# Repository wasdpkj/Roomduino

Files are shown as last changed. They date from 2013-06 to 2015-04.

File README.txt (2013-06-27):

=================================
本作品采用知识共享 署名-非商业性使用-相同方式共享 3.0 未本地化版本 许可协议进行许可。
访问 http://creativecommons.org/licenses/by-nc-sa/3.0/ 查看该许可协议。
=================================

硬件：
主机：MCU：MEGA644PA，网络芯片：ENC28J60，RJ45网口：HR911105A，2.4G无线：nRF24L01，显示屏：NOKIA5110屏，红外接收头
副机：MCU：MEGA328P或者168PA，2.4G无线：nRF24L01，可控硅：BT136，光耦：MOC3041
{副机可以自行选择设计成节点式（既一个arduino+24L01控制一个开关节点）、还是单MCU多路式（既一个arduino+24L01控制四个开关）}

除了以上条件，你还需要一个路由器，一个YEELINK账号，和一个红外遥控器。

========================================================
软件：

配置：
比如我的路由器网关是192.168.1，那么主机程序段里设置成如下即可，第一个是主机的IP地址，这个要和本地网页中的IP地址匹配

static byte myip[] =
{
  192, 168, 1, 121
};
static byte gwip[] =
{
  192, 168, 1, 1
};
static byte dnsip[] =
{
  192, 168, 1, 1
};

然后YEELINK的ID：
urlBuf0[]是YEELINK控制开关地址，剩下的是四个节点，然后填好你的API就可以

char website[] PROGMEM = "api.yeelink.net";

char urlBuf0[] PROGMEM = "/v1.0/device/xxx/sensor/xxx/";

char urlBuf1[] PROGMEM = "/v1.0/device/xxx/sensor/xxx/";
char urlBuf2[] PROGMEM = "/v1.0/device/xxx/sensor/xxx/";
char urlBuf3[] PROGMEM = "/v1.0/device/xxx/sensor/xxx/";
char urlBuf4[] PROGMEM = "/v1.0/device/xxx/sensor/xxx/";

char apiKey[] PROGMEM = "U-ApiKey: xxx";

================================================

说说红外遥控的使用：
开机进入系统后：
按“1”“2”“3”“4”可以开关四路节点；
按“PLAY”也可以实现系统模式切换（YEELINK万维网控制还是本地手动控制）；
按“CH+”“CH-”“CH”可以选择相应节点并且执行倒计时功能。

按“EQ”即可进入设置，此时“0”为确认，“+”和“-”上下移动菜单，再次按“EQ”结束设置：
设置的第一项“CONFIG MOD”是切换系统模式，这个在主界面按PLAY也可以实现切换。
设置的第二项“CONFIG TIME”是预约开启的设置，选择对应节点后，第一项是否定时开启，第二项与第三项是定时开启的时间设置，第四项是定时开启的世界设置（单位分钟）。
设置的第三项“CONFIG DS”是倒计时的设置，选择对应节点后，即可设置倒计时时间（单位分钟），此时“+”“-”“NEXT”“PREV”分别是加1，减1，加10，减10。
设置的第四项“CONFIG CON”是配置节点用的，选择所需配置节点后，系统会提示按下你所需节点的配置按键2秒以上，此时你能看到节点上的状态灯快速闪烁的话，就配置成功了；对了，工作模式下，节点上的灯闪动次数对应着第几路。
设置的第五项“CONFIG INFO”是系统信息和about

================================================

关于本地局域网控制的web网页：
你可以用编辑器打开index.html，里面的“http://192.168.1.121”就是当前arduino主机对应的IP地址；
另外，由于jquery的安全限制，现在仅支持PC端谷歌浏览器和ios端的谷歌浏览器的正常使用。

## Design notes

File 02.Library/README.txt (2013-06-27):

pkj是自己写的简单库
功能是限定/跳转值的上下限

ethercard库的推送方式我自己改过

大概如下：
char website[] PROGMEM = "api.yeelink.net";
char urlBuf0[] PROGMEM = "/v1.0/device/xxx/sensor/xxx/";
char apiKey[] PROGMEM = "U-ApiKey: xxx";

static void my_result_cb (byte status, word off, word len)
{
  sscanf((char *)strstr((const char *)Ethernet::buffer + off, "\"value\""), "\"value\":%d", &yee[yeenum-1]);    //采集关键字数据
}

          ether.browseUrl(urlBuf, "datapoints", website, apiKey, my_result_cb);   //采集节点

          ether.httpPost (urlBuf, "datapoints", website, apiKey, "{\"value\":0}", my_result_cb);    //把节点推到关

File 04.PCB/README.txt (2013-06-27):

重点说一下“副机 多路式”这个PCB
此PCB设计了ISP刷机口，预留了24L01插口、霍尔元件接口、SD卡、音频口、串口。随你怎么用

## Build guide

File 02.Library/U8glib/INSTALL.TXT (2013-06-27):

U8GLIB
http://code.google.com/p/u8glib/

Install instructions for the Arduino environment.

  1. Unzip u8glib_arduino_vX.XX.zip into the "libraries" folder
  2. Start Arduino IDE

Install instructions for the Chipkit (Arduino) environment.

  1. cd <mpide-... path>/libraries
  2. unzip u8glib_arduino_vX.XX.zip
  3. cd <mpide-... path>///hardware/pic32/libraries
  4. again: u8glib_arduino_vX.XX.zip
  5. Open hardware/pic32/cores/pic32/Print.h
	  Remove line
	    #define BYTE 0
	  from the file, use PRINT_BYTE instead of BYTE.

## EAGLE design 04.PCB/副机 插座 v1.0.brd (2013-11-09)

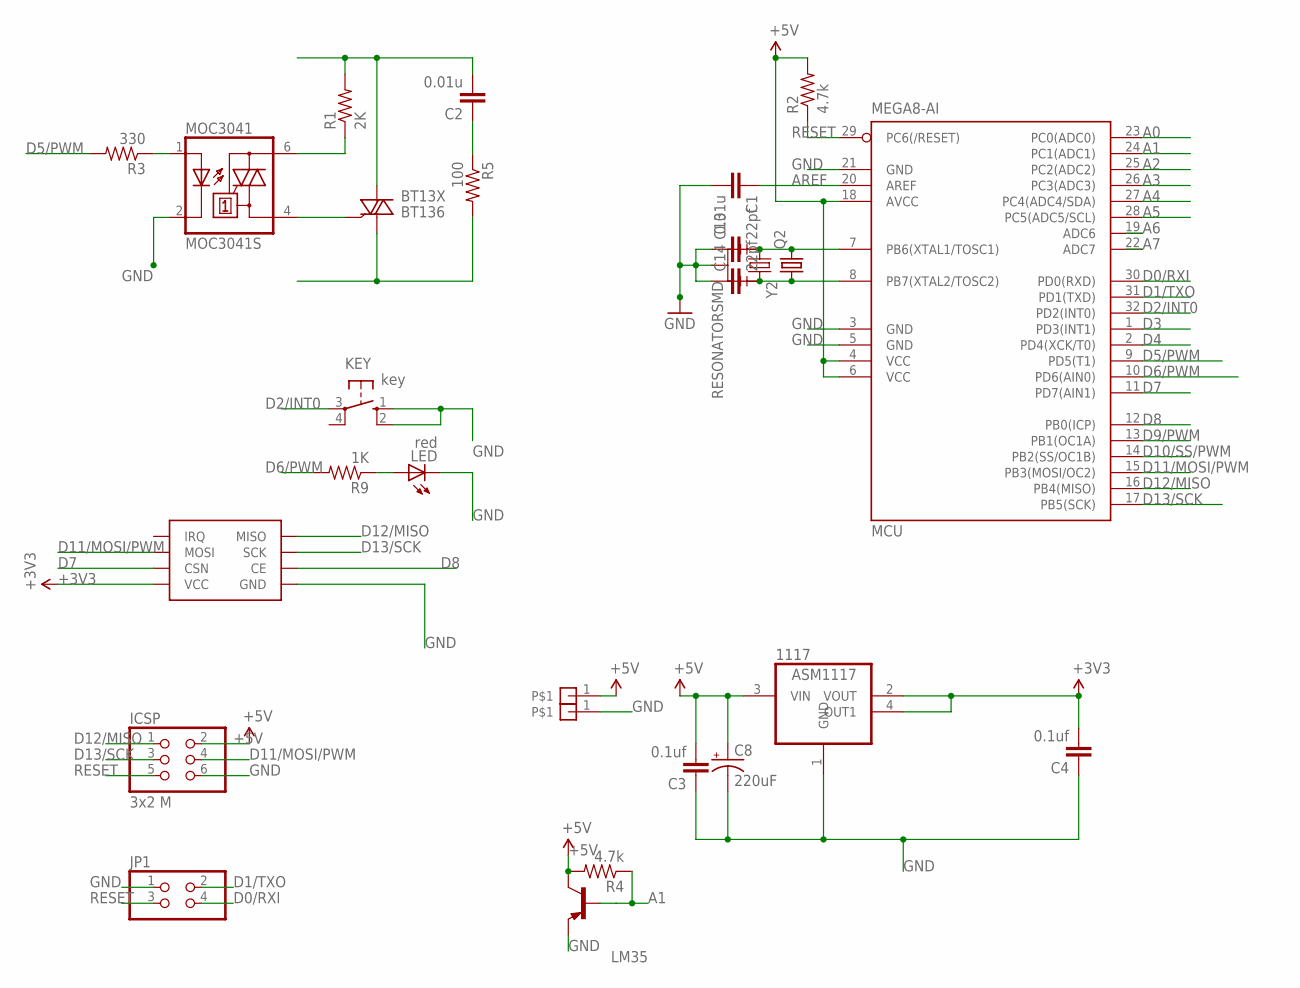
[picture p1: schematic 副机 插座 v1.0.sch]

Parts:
1117: ASM1117; SOT223
BT13X: BT136; TO252
C1: 0.01u; 0603-CAP
C2: 0.01u; C050-024X044
C3, C4: 0.1uf; 0603-CAP
C8: 220uF; EIA3528
C13, C14: 22pf; 0603-CAP
ICSP: 3x2 M; 2X03
JP1: PINHD-2X2; 2X02
KEY: key; B3F-10XX; MPN B3F-1000
LED: red; LED3MM
LM35: -PNP-TO92-E1; TO92-E1
MCU: MEGA8-AI; TQFP32-08
MOC3041: MOC3041S; DIL6-SMD; MPN MOC3041S-M
Q2: CRYSTALHC49S; HC49/S
R1: 2K; AXIAL-0.3
R2, R4: 4.7k; 0603-RES
R3: 330; 0603-RES
R5: 100; AXIAL-0.3
R9: 1K; 0603-RES
U$3, U$4: PIN1
U$6: NRF
Y2: RESONATORSMD; RESONATOR-SMD

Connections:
+3V3: 1117.2 (VOUT), 1117.4 (OUT1), C4.2, U$6.P$2 (VCC)
+5V: 1117.3 (VIN), C3.2, C8.A (+), ICSP.2, LM35.1 (C), MCU.4 (VCC), MCU.6 (VCC), MCU.18 (AVCC), R2.2, R4.2, U$3.1
A0: MCU.23 (PC0(ADC0))
A1: LM35.2 (B), MCU.24 (PC1(ADC1)), R4.1
A2: MCU.25 (PC2(ADC2))
A3: MCU.26 (PC3(ADC3))
A4: MCU.27 (PC4(ADC4/SDA))
A5: MCU.28 (PC5(ADC5/SCL))
A6: MCU.19 (ADC6)
A7: MCU.22 (ADC7)
AREF: C1.1, MCU.20 (AREF)
D0/RXI: JP1.4, MCU.30 (PD0(RXD))
D1/TXO: JP1.2, MCU.31 (PD1(TXD))
D2/INT0: KEY.3, MCU.32 (PD2(INT0))
D3: MCU.1 (PD3(INT1))
D4: MCU.2 (PD4(XCK/T0))
D5/PWM: MCU.9 (PD5(T1)), R3.2
D6/PWM: MCU.10 (PD6(AIN0)), R9.2
D7: MCU.11 (PD7(AIN1)), U$6.P$4 (CSN)
D8: MCU.12 (PB0(ICP)), U$6.P$3 (CE)
D9/PWM: MCU.13 (PB1(OC1A))
D10/SS/PWM: MCU.14 (PB2(SS/OC1B))
D11/MOSI/PWM: ICSP.4, MCU.15 (PB3(MOSI/OC2)), U$6.P$6 (MOSI)
D12/MISO: ICSP.1, MCU.16 (PB4(MISO)), U$6.P$7 (MISO)
D13/SCK: ICSP.3, MCU.17 (PB5(SCK)), U$6.P$5 (SCK)
GND: 1117.1 (GND), C1.2, C3.1, C4.1, C8.C (-), C13.1, C14.1, ICSP.6, JP1.1, KEY.1 (S), KEY.2 (S1), LED.K (C), LM35.3 (E), MCU.3 (GND), MCU.5 (GND), MCU.21 (GND), MOC3041.2 (C), U$4.1, U$6.P$1 (GND), Y2.2
IN: BT13X.3 (A2), C2.2, R1.P$2 (2)
unnamed: MOC3041.6 (A2), R1.P$1 (1)
unnamed: BT13X.2 (G), MOC3041.4 (A1)
unnamed: C2.1, R5.P$1 (1)
unnamed: LED.A, R9.1
unnamed: C13.2, MCU.7 (PB6(XTAL1/TOSC1)), Q2.2, Y2.1
unnamed: C14.2, MCU.8 (PB7(XTAL2/TOSC2)), Q2.1, Y2.3
OUT: BT13X.1 (A1), R5.P$2 (2)
P1: MOC3041.1 (A), R3.1
RESET: ICSP.5, JP1.3, MCU.29 (PC6(/RESET)), R2.1

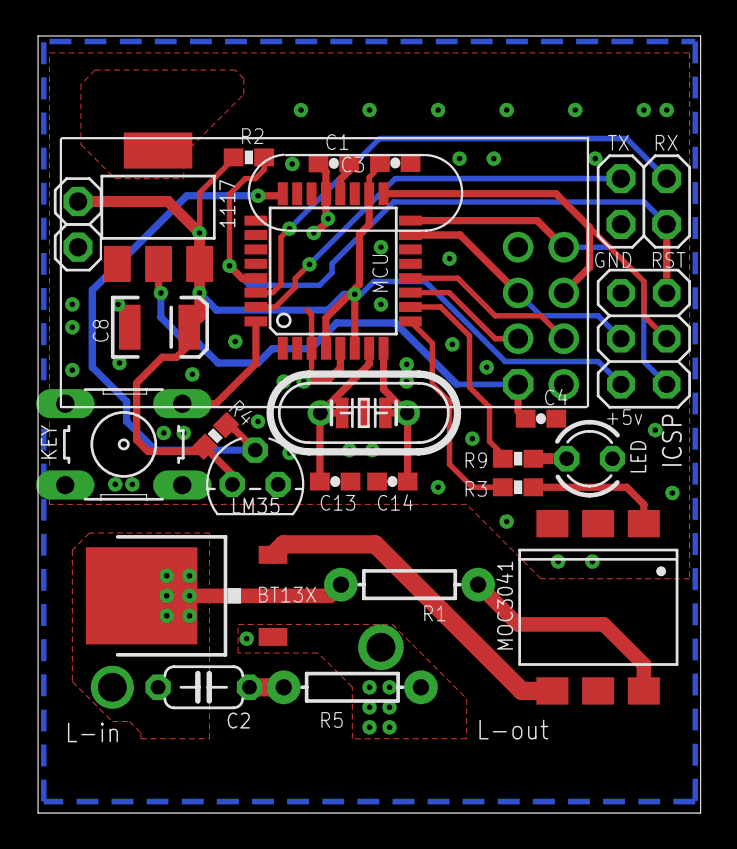
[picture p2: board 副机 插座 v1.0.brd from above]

Board: 2 copper layers, 36.8 x 43.2 mm, 27 parts (0 on the bottom side), 25 nets.

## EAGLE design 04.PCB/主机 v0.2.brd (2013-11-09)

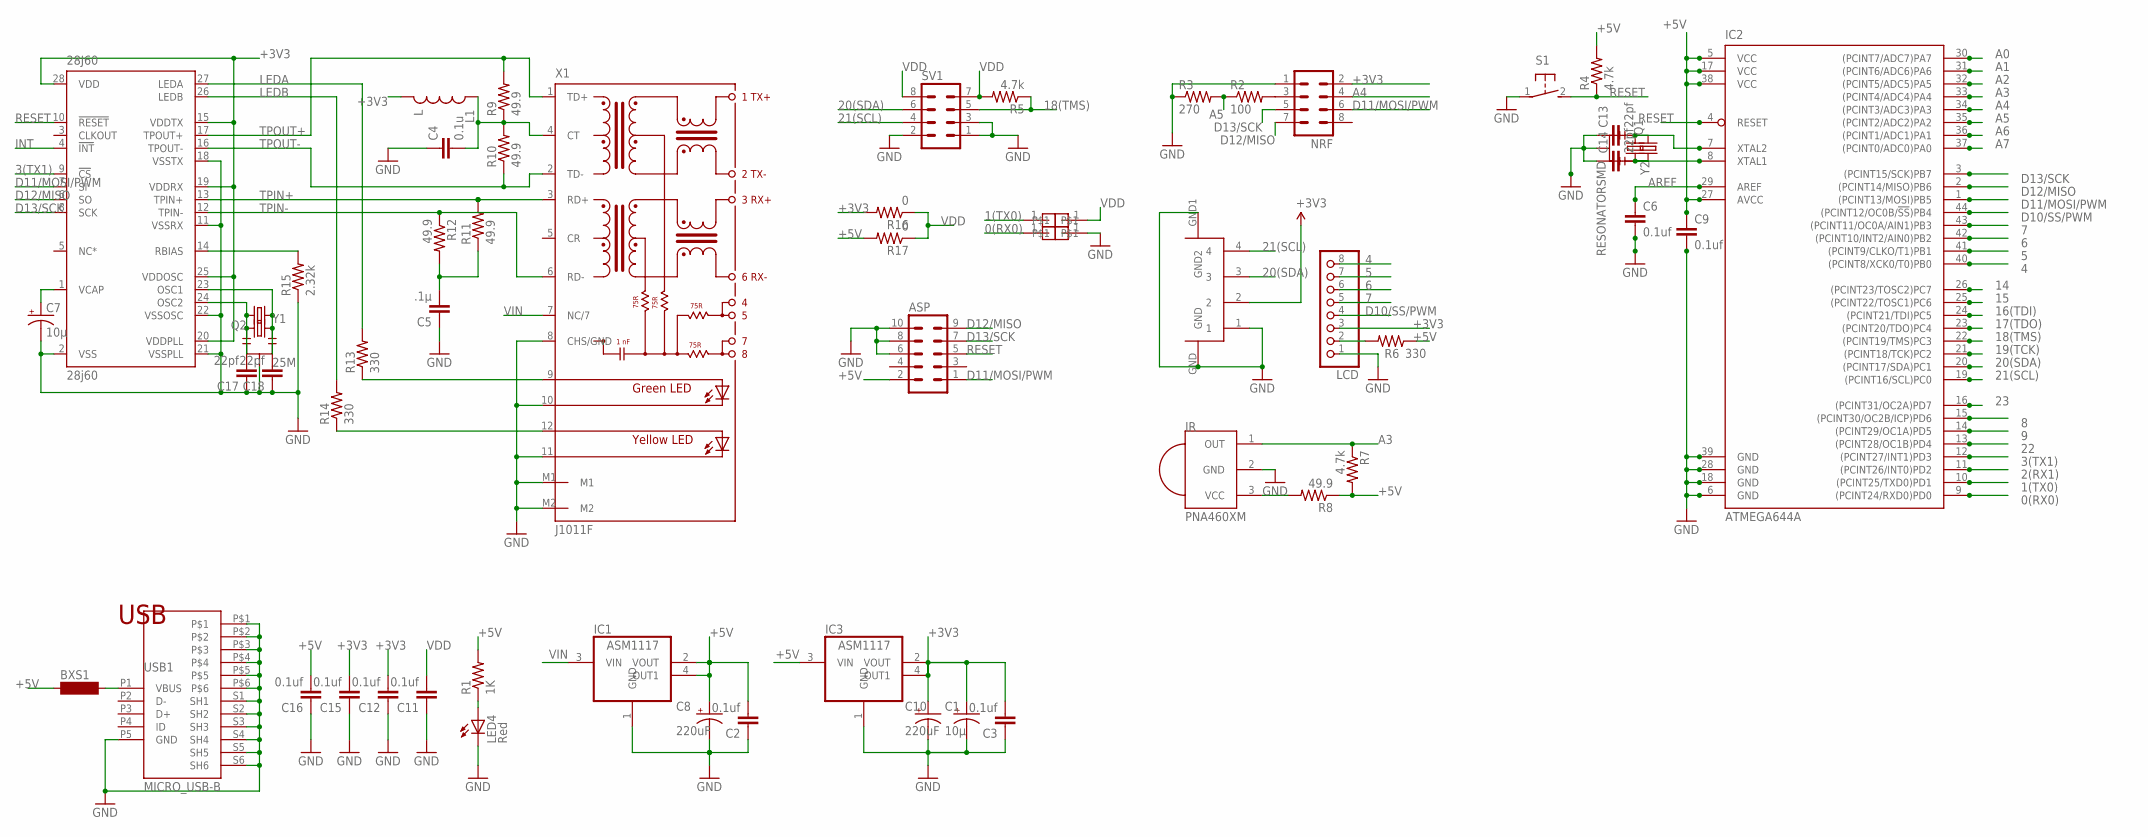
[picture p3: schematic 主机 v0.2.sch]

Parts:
28J60: 28j60; SSOP28DB
ASP: MA05-2
BXS1: SM-1206
C1, C7: 10µ; EIA3528
C2, C3, C6, C9, C11, C12, C15, C16: 0.1uf; 0603-CAP
C4: 0.1u; 0603-CAP
C5: .1µ; 0603-CAP
C8, C10: 220uF; 153CLV-0605
C13, C14, C17, C18: 22pf; 0603-CAP
IC1: ASM1117; SOT223
IC2: ATMEGA644A; TQFP44
IC3: ASM1117; SOT223; MPN REG1117
IR: PNA460XM
L1: L; 0603
LCD: PINHD-1X8; 1X08
LED4: Red; 0805-LED
NRF: MA04-2
Q1, Q2: CRYSTALHC49S; HC49/S
R1: 1K; 0603-RES
R2: 100; 0603-RES
R3: 270; 0603-RES
R4, R5, R7: 4.7k; 0603-RES
R6, R13, R14: 330; 0603-RES
R8, R9, R10, R11, R12: 49.9; 0603-RES
R15: 2.32k; 0603-RES
R16, R17: 0; 0603-RES
S1: 31-XX; B3F-31XX
SV1: MA04-2
U$2: S4B-XH-SM4-TB; XH-SM4-TB
U$4, U$5, U$6, U$7: PIN1
USB1: MICRO_USB-B; USB_MICRO_B
X1: J1011F; HRJ
Y1: 25M; RESONATOR-SMD
Y2: RESONATORSMD; RESONATOR-SMD

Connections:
0(RX0): IC2.9 ((PCINT24/RXD0)PD0), U$7.1
1(TX0): IC2.10 ((PCINT25/TXD0)PD1), U$6.1
2(RX1): IC2.11 ((PCINT26/INT0)PD2)
3(TX1): 28J60.9 (!CS), IC2.12 ((PCINT27/INT1)PD3)
4: IC2.40 ((PCINT8/XCK0/T0)PB0), LCD.8
5: IC2.41 ((PCINT9/CLKO/T1)PB1), LCD.7
6: IC2.42 ((PCINT10/INT2/AIN0)PB2), LCD.6
7: IC2.43 ((PCINT11/OC0A/AIN1)PB3), LCD.5
8: IC2.15 ((PCINT30/OC2B/ICP)PD6)
9: IC2.14 ((PCINT29/OC1A)PD5)
14: IC2.26 ((PCINT23/TOSC2)PC7)
15: IC2.25 ((PCINT22/TOSC1)PC6)
16(TDI): IC2.24 ((PCINT21/TDI)PC5)
17(TDO): IC2.23 ((PCINT20/TDO)PC4)
18(TMS): IC2.22 ((PCINT19/TMS)PC3), R5.1, SV1.5
19(TCK): IC2.21 ((PCINT18/TCK)PC2)
20(SDA): IC2.20 ((PCINT17/SDA)PC1), SV1.6, U$2.3
21(SCL): IC2.19 ((PCINT16/SCL)PC0), SV1.4, U$2.4
22: IC2.13 ((PCINT28/OC1B)PD4)
23: IC2.16 ((PCINT31/OC2A)PD7)
+3V3: 28J60.15 (VDDTX), 28J60.19 (VDDRX), 28J60.20 (VDDPLL), 28J60.25 (VDDOSC), 28J60.28 (VDD), C1.A (+), C3.2, C10.+, C12.2, C15.2, IC3.2 (VOUT), IC3.4 (OUT1), L1.2, LCD.3, NRF.2, R16.2, U$2.2
+5V: ASP.2, BXS1.1, C2.2, C8.+, C9.1, C16.2, IC1.2 (VOUT), IC1.4 (OUT1), IC2.5 (VCC), IC2.17 (VCC), IC2.27 (AVCC), IC2.38 (VCC), IC3.3 (VIN), R1.2, R4.2, R6.1, R7.2, R8.1, R17.2
A0: IC2.30 ((PCINT7/ADC7)PA7)
A1: IC2.31 ((PCINT6/ADC6)PA6)
A2: IC2.32 ((PCINT5/ADC5)PA5)
A3: IC2.33 ((PCINT4/ADC4)PA4), IR.1 (OUT), R7.1
A4: IC2.34 ((PCINT3/ADC3)PA3), NRF.4
A5: IC2.35 ((PCINT2/ADC2)PA2), R2.1, R3.2
A6: IC2.36 ((PCINT1/ADC1)PA1)
A7: IC2.37 ((PCINT0/ADC0)PA0)
AREF: C6.1, IC2.29 (AREF)
D10/SS/PWM: IC2.44 ((PCINT12/OC0B/!SS!)PB4), LCD.4
D11/MOSI/PWM: 28J60.7 (SI), ASP.1, IC2.1 ((PCINT13/MOSI)PB5), NRF.6
D12/MISO: 28J60.6 (SO), ASP.9, IC2.2 ((PCINT14/MISO)PB6), NRF.7
D13/SCK: 28J60.8 (SCK), ASP.7, IC2.3 ((PCINT15/SCK)PB7), NRF.5
GND: 28J60.2 (VSS), 28J60.11 (VSSRX), 28J60.18 (VSSTX), 28J60.21 (VSSPLL), 28J60.22 (VSSOSC), ASP.6, ASP.8, ASP.10, C1.C (-), C2.1, C3.1, C4.1, C5.1, C6.2, C7.C (-), C8.-, C9.2, C10.-, C11.1, C12.1, C13.1, C14.1, C15.1, C16.1, C17.1, C18.1, IC1.1 (GND), IC2.6 (GND), IC2.18 (GND), IC2.28 (GND), IC2.39 (GND), IC3.1 (GND), IR.2 (GND), LCD.1, LED4.C, NRF.1, R3.1, R15.1, S1.1, SV1.1, SV1.2, SV1.3, U$2.1, U$2.GND, U$2.GND1 (GND2), U$4.1, USB1.P5 (GND), USB1.P$1, USB1.P$2, USB1.P$3, USB1.P$4, USB1.P$5, USB1.P$6, USB1.S1 (SH1), USB1.S2 (SH2), USB1.S3 (SH3), USB1.S4 (SH4), USB1.S5 (SH5), USB1.S6 (SH6), X1.8 (CHS/GND), X1.10 (C-R), X1.11 (C-L), X1.M1, X1.M2, Y1.2, Y2.2
INT: 28J60.4 (!INT)
LEDA: 28J60.27 (LEDA), R13.2
LEDB: 28J60.26 (LEDB), R14.2
unnamed: C13.2, IC2.7 (XTAL2), Q1.2, Y2.1
unnamed: IR.3 (VCC), R8.2
unnamed: LED4.A, R1.1
unnamed: NRF.3, R2.2
unnamed: C5.2, R11.1, R12.2
unnamed: 28J60.1 (VCAP), C7.A (+)
unnamed: 28J60.14 (RBIAS), R15.2
unnamed: C14.2, IC2.8 (XTAL1), Q1.1, Y2.3
unnamed: C4.2, L1.1, R9.1, R10.2, X1.4 (CT)
unnamed: 28J60.24 (OSC2), C17.2, Q2.2, Y1.1
unnamed: 28J60.23 (OSC1), C18.2, Q2.1, Y1.3
unnamed: R13.1, X1.9 (A-R)
unnamed: R14.1, X1.12 (AL)
unnamed: LCD.2, R6.2
RESET: 28J60.10 (!RESET), ASP.5, IC2.4 (RESET), R4.1, S1.2 (S)
TPIN+: 28J60.13 (TPIN+), R11.2, X1.3 (RD+)
TPIN-: 28J60.12 (TPIN-), R12.1, X1.6 (RD-)
TPOUT+: 28J60.17 (TPOUT+), R9.2, X1.1 (TD+)
TPOUT-: 28J60.16 (TPOUT-), R10.1, X1.2 (TD-)
VDD: C11.2, R5.2, R16.1, R17.1, SV1.7, SV1.8, U$5.1
VIN: IC1.3 (VIN), X1.7 (NC/7)
VUSB: BXS1.2, USB1.P1 (VBUS)

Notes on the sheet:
USB

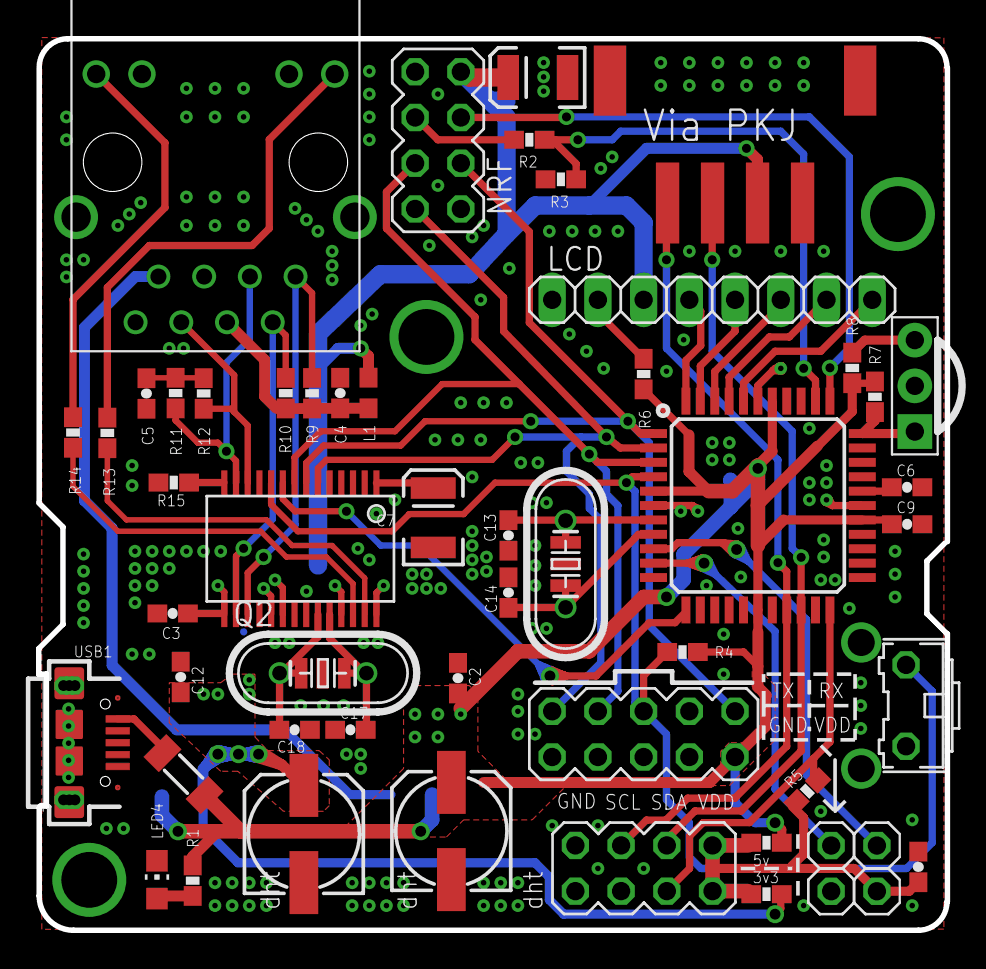
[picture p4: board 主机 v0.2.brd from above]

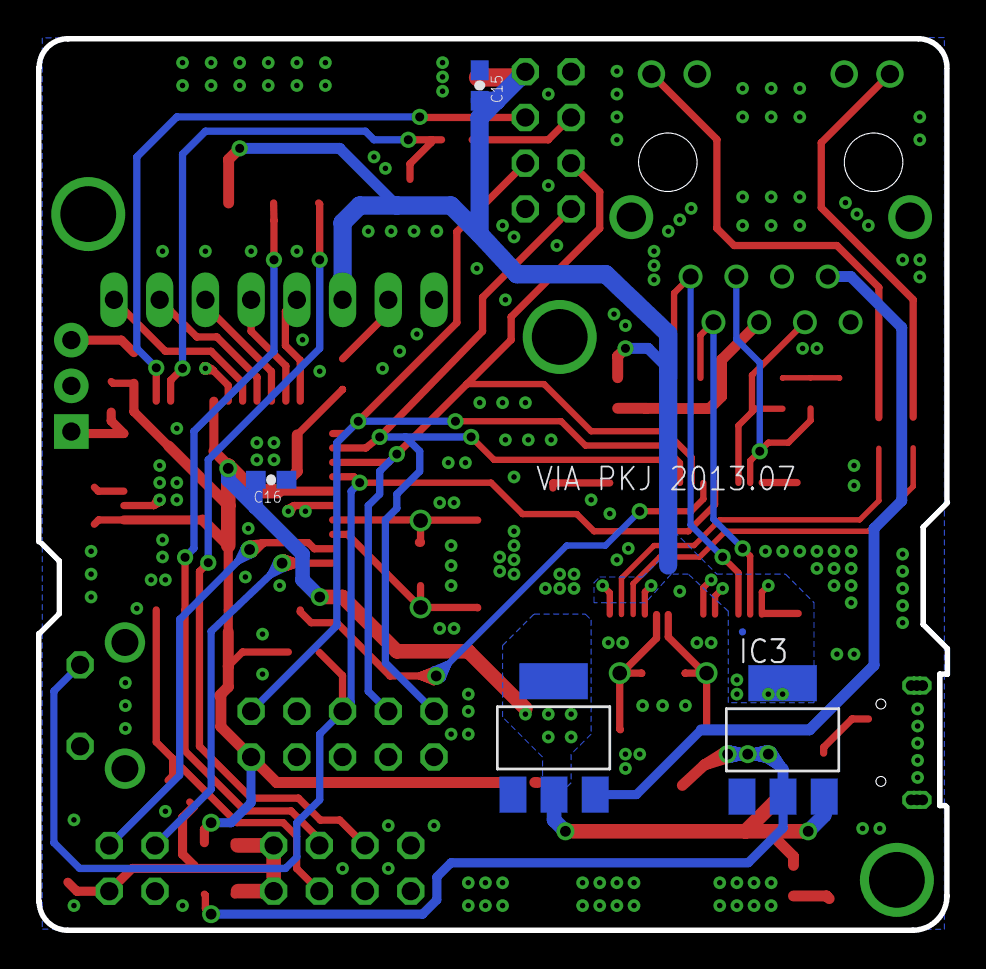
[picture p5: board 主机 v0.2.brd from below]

Board: 2 copper layers, 50.5 x 49.5 mm, 59 parts (4 on the bottom side), 45 nets.

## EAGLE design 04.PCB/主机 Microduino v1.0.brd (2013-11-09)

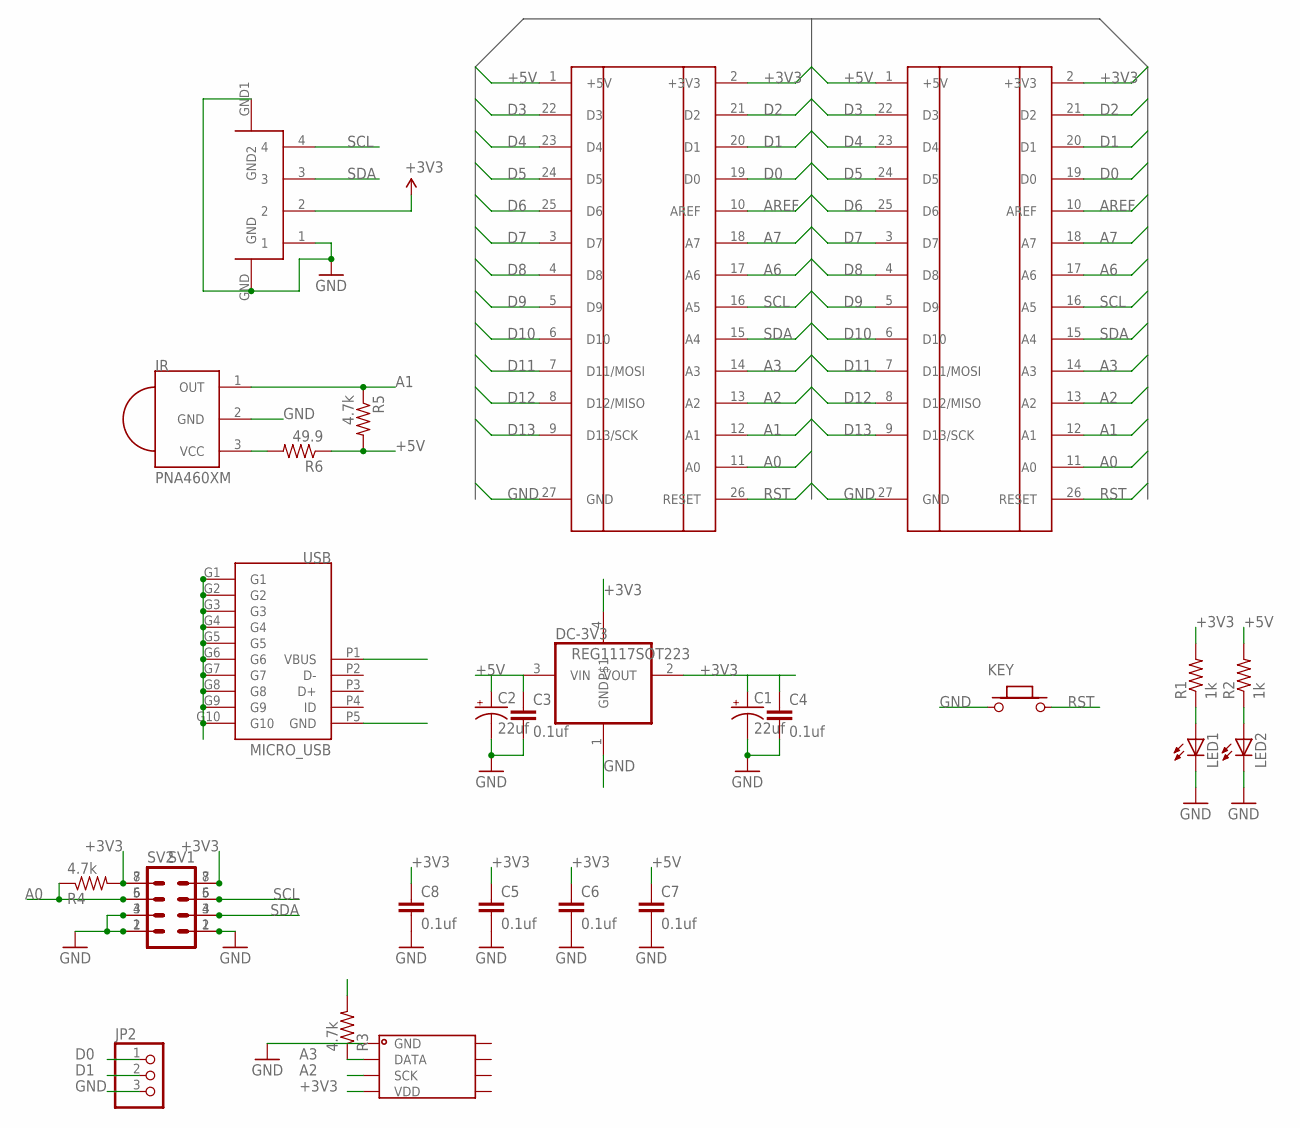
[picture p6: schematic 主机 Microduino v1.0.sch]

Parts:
C1, C2: 22uf; EIA3216
C3, C4, C5, C6, C7, C8: 0.1uf; 0603-CAP
DC-3V3: REG1117SOT223; SOT223
IR: PNA460XM
JP2: PINHD-1X3; 1X03
KEY: KEY-TES-018; KEY-TS-018
LED1, LED2: LED0805; 0805-LED
R1, R2: 1k; 0603-RES
R3, R4, R5: 4.7k; 0603-RES
R6: 49.9; 0603-RES
SV1, SV2: MA04-2
U$1, U$2: PING-MICRDUINO/1009+; PIN-MICRODUINO-1009
U$3: S4B-XH-SM4-TB; XH-SM4-TB
U$4: SHT11
USB: MICRO_USB; MICRO_USB_LJ

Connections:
+3V3: C1.A (+), C4.1, C5.1, C6.1, C8.1, DC-3V3.2 (VOUT), DC-3V3.4, R1.2, R3.2, R4.2, SV1.7, SV1.8, SV2.7, SV2.8, U$1.2 (+3V3), U$2.2 (+3V3), U$3.2, U$4.4 (VDD)
+5V: C2.A (+), C3.1, C7.1, DC-3V3.3 (VIN), R2.2, R5.2, R6.1, U$1.1 (+5V), U$2.1 (+5V), USB.P1 (VBUS)
A0: R4.1, SV1.5, SV2.6, U$1.11 (A0), U$2.11 (A0)
A1: IR.1 (OUT), R5.1, U$1.12 (A1), U$2.12 (A1)
A2: U$1.13 (A2), U$2.13 (A2), U$4.3 (SCK)
A3: R3.1, U$1.14 (A3), U$2.14 (A3), U$4.2 (DATA)
A6: U$1.17 (A6), U$2.17 (A6)
A7: U$1.18 (A7), U$2.18 (A7)
AREF: U$1.10 (AREF), U$2.10 (AREF)
D0: JP2.1, U$1.19 (D0), U$2.19 (D0)
D1: JP2.2, U$1.20 (D1), U$2.20 (D1)
D2: U$1.21 (D2), U$2.21 (D2)
D3: U$1.22 (D3), U$2.22 (D3)
D4: U$1.23 (D4), U$2.23 (D4)
D5: U$1.24 (D5), U$2.24 (D5)
D6: U$1.25 (D6), U$2.25 (D6)
D7: U$1.3 (D7), U$2.3 (D7)
D8: U$1.4 (D8), U$2.4 (D8)
D9: U$1.5 (D9), U$2.5 (D9)
D10: U$1.6 (D10), U$2.6 (D10)
D11: U$1.7 (D11/MOSI), U$2.7 (D11/MOSI)
D12: U$1.8 (D12/MISO), U$2.8 (D12/MISO)
D13: U$1.9 (D13/SCK), U$2.9 (D13/SCK)
GND: C1.C (-), C2.C (-), C3.2, C4.2, C5.2, C6.2, C7.2, C8.2, DC-3V3.1 (GND), IR.2 (GND), JP2.3, KEY.2 (1), LED1.C, LED2.C, SV1.1, SV1.2, SV1.3, SV2.1, SV2.2, SV2.4, U$1.27 (GND), U$2.27 (GND), U$3.1, U$3.GND, U$3.GND1 (GND2), U$4.1 (GND), USB.G1, USB.G2, USB.G3, USB.G4, USB.G5, USB.G6, USB.G7, USB.G8, USB.G9, USB.G10, USB.P5 (GND)
unnamed: IR.3 (VCC), R6.2
unnamed: LED1.A, R1.1
unnamed: LED2.A, R2.1
RST: KEY.1 (2), U$1.26 (RESET), U$2.26 (RESET)
SCL: SV1.6, SV2.5, U$1.16 (A5), U$2.16 (A5), U$3.4
SDA: SV1.4, SV2.3, U$1.15 (A4), U$2.15 (A4), U$3.3

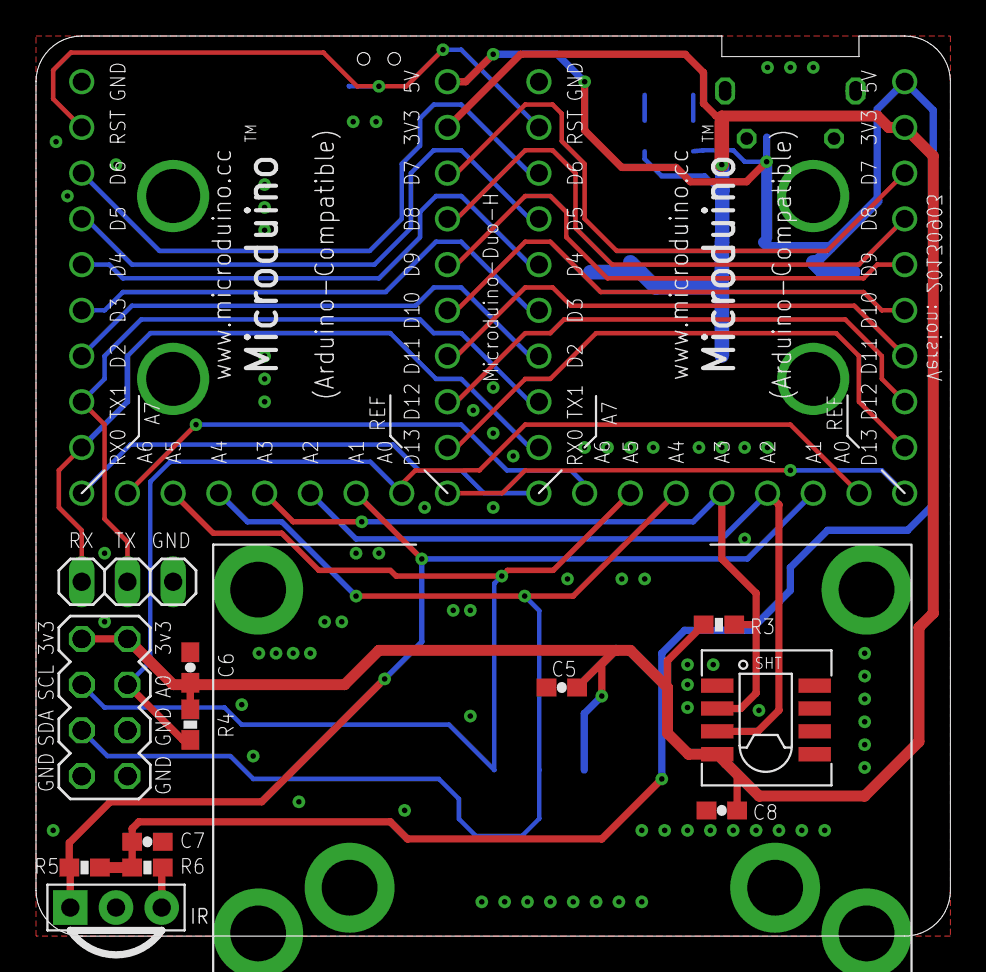
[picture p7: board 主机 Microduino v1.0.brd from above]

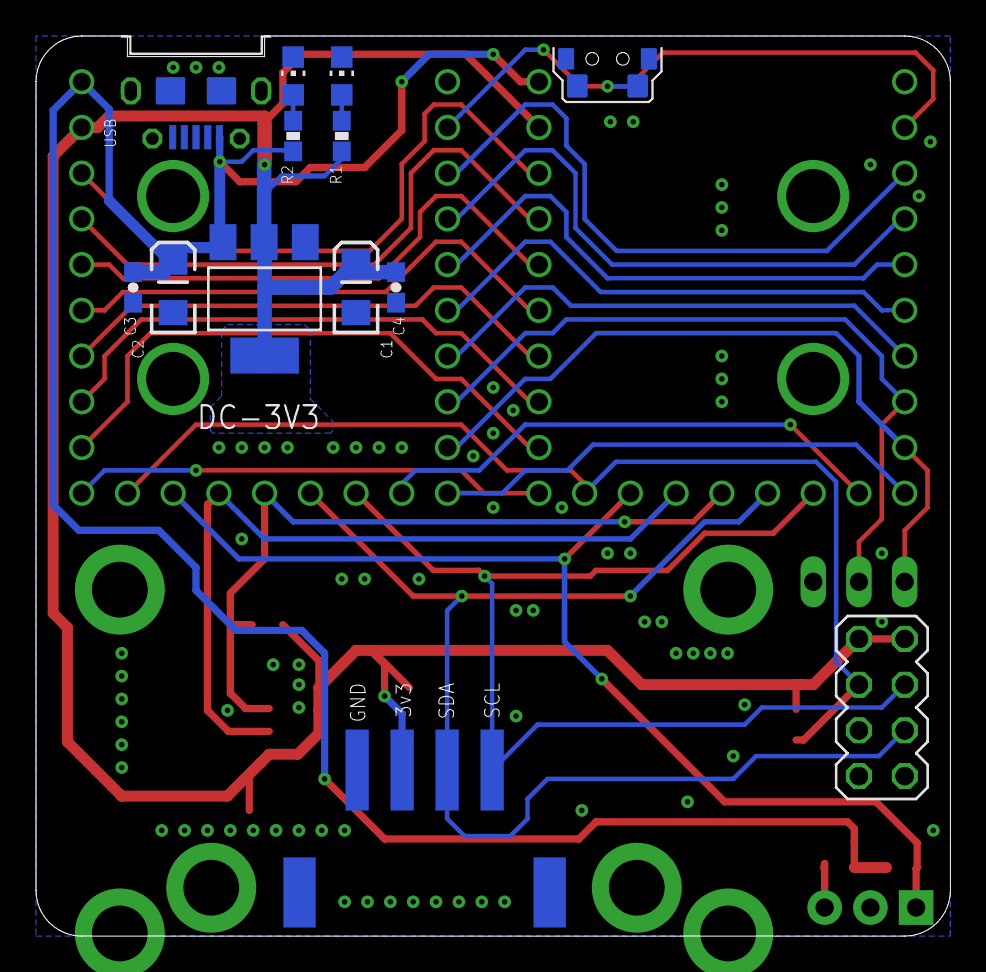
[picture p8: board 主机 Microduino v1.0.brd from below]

Board: 2 copper layers, 50.8 x 50.0 mm, 27 parts (15 on the bottom side), 30 nets.

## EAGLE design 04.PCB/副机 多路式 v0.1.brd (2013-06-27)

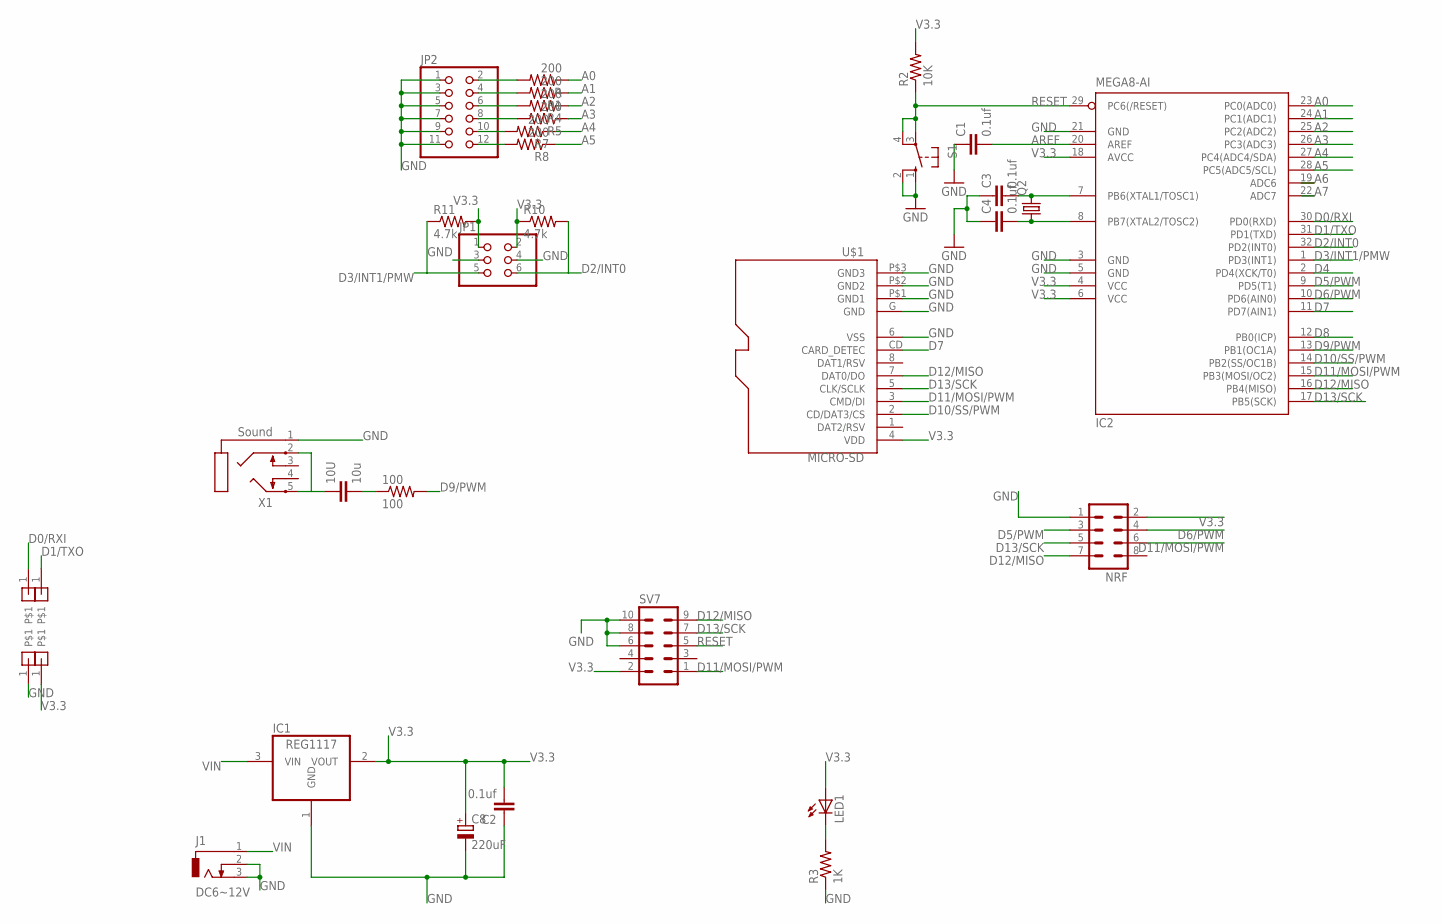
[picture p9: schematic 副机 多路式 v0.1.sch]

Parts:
10U: 10u; C050-024X044
100: 100; 0603-RES
C1, C2, C3, C4: 0.1uf; 0603-CAP
C8: 220uF; 153CLV-0605
IC1: REG1117; SOT223
IC2: MEGA8-AI; TQFP32-08
J1: DC6~12V; DCJ0202
JP1: PINHD-2X3; 2X03
JP2: PINHD-2X6; 2X06
LED1: LED0805; 0805-LED
NRF: MA04-2
Q2: CRYSTALHC49S; HC49/S
R, R1, R4, R5, R7, R8: 200; 0603-RES
R2: 10K; 0603-RES
R3: 1K; 0603-RES
R10, R11: 4.7k; 0603-RES
S1: 10-XX; B3F-10XX
SV7: MA05-2
U$1: MICRO-SD
U$4, U$5, U$6, U$7: PIN1
X1: Sound; STX3100

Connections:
A0: IC2.23 (PC0(ADC0)), R.1
A1: IC2.24 (PC1(ADC1)), R1.1
A2: IC2.25 (PC2(ADC2)), R4.1
A3: IC2.26 (PC3(ADC3)), R5.1
A4: IC2.27 (PC4(ADC4/SDA)), R7.1
A5: IC2.28 (PC5(ADC5/SCL)), R8.1
A6: IC2.19 (ADC6)
A7: IC2.22 (ADC7)
AREF: C1.2, IC2.20 (AREF)
D0/RXI: IC2.30 (PD0(RXD)), U$7.1
D1/TXO: IC2.31 (PD1(TXD)), U$6.1
D2/INT0: IC2.32 (PD2(INT0)), JP1.6, R10.2
D3/INT1/PMW: IC2.1 (PD3(INT1)), JP1.5, R11.1
D4: IC2.2 (PD4(XCK/T0))
D5/PWM: IC2.9 (PD5(T1)), NRF.3
D6/PWM: IC2.10 (PD6(AIN0)), NRF.4
D7: IC2.11 (PD7(AIN1)), U$1.CD (CARD_DETEC)
D8: IC2.12 (PB0(ICP))
D9/PWM: 100.2, IC2.13 (PB1(OC1A))
D10/SS/PWM: IC2.14 (PB2(SS/OC1B)), U$1.2 (CD/DAT3/CS)
D11/MOSI/PWM: IC2.15 (PB3(MOSI/OC2)), NRF.6, SV7.1, U$1.3 (CMD/DI)
D12/MISO: IC2.16 (PB4(MISO)), NRF.7, SV7.9, U$1.7 (DAT0/DO)
D13/SCK: IC2.17 (PB5(SCK)), NRF.5, SV7.7, U$1.5 (CLK/SCLK)
GND: C1.1, C2.1, C3.1, C4.1, C8.-, IC1.1 (GND), IC2.3 (GND), IC2.5 (GND), IC2.21 (GND), J1.2, J1.3, JP1.3, JP1.4, JP2.1, JP2.3, JP2.5, JP2.7, JP2.9, JP2.11, NRF.1, R3.1, S1.1 (S), S1.2 (S1), SV7.6, SV7.8, SV7.10, U$1.6 (VSS), U$1.G (GND), U$1.P$1 (GND1), U$1.P$2 (GND2), U$1.P$3 (GND3), U$4.1, X1.1
unnamed: JP2.2, R.2
unnamed: JP2.12, R8.2
unnamed: JP2.4, R1.2
unnamed: LED1.C, R3.2
unnamed: JP2.6, R4.2
unnamed: JP2.8, R5.2
unnamed: JP2.10, R7.2
unnamed: 10U.2, 100.1
PB6: C3.2, IC2.7 (PB6(XTAL1/TOSC1)), Q2.2
PB7: C4.2, IC2.8 (PB7(XTAL2/TOSC2)), Q2.1
RESET: IC2.29 (PC6(/RESET)), R2.1, S1.3, S1.4 (P1), SV7.5
V3.3: C2.2, C8.+, IC1.2 (VOUT), IC2.4 (VCC), IC2.6 (VCC), IC2.18 (AVCC), JP1.1, JP1.2, LED1.A, NRF.2, R2.2, R10.1, R11.2, SV7.2, U$1.4 (VDD), U$5.1
VIN: IC1.3 (VIN), J1.1
~~: 10U.1, X1.2, X1.5

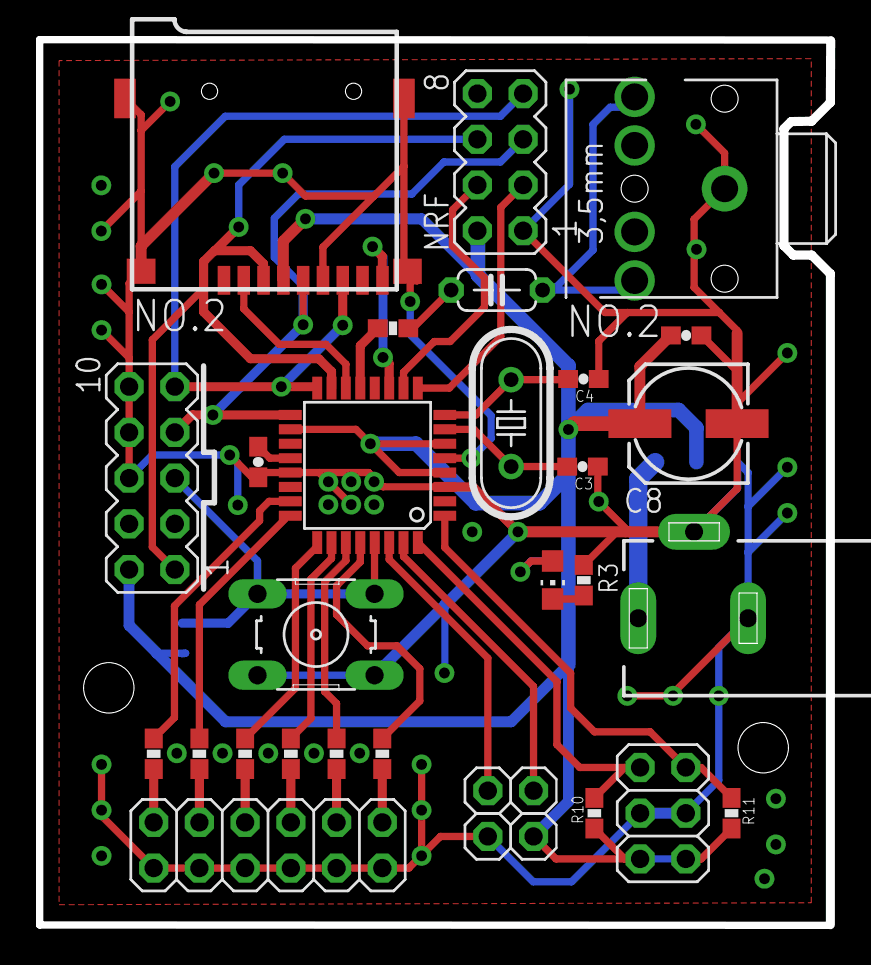
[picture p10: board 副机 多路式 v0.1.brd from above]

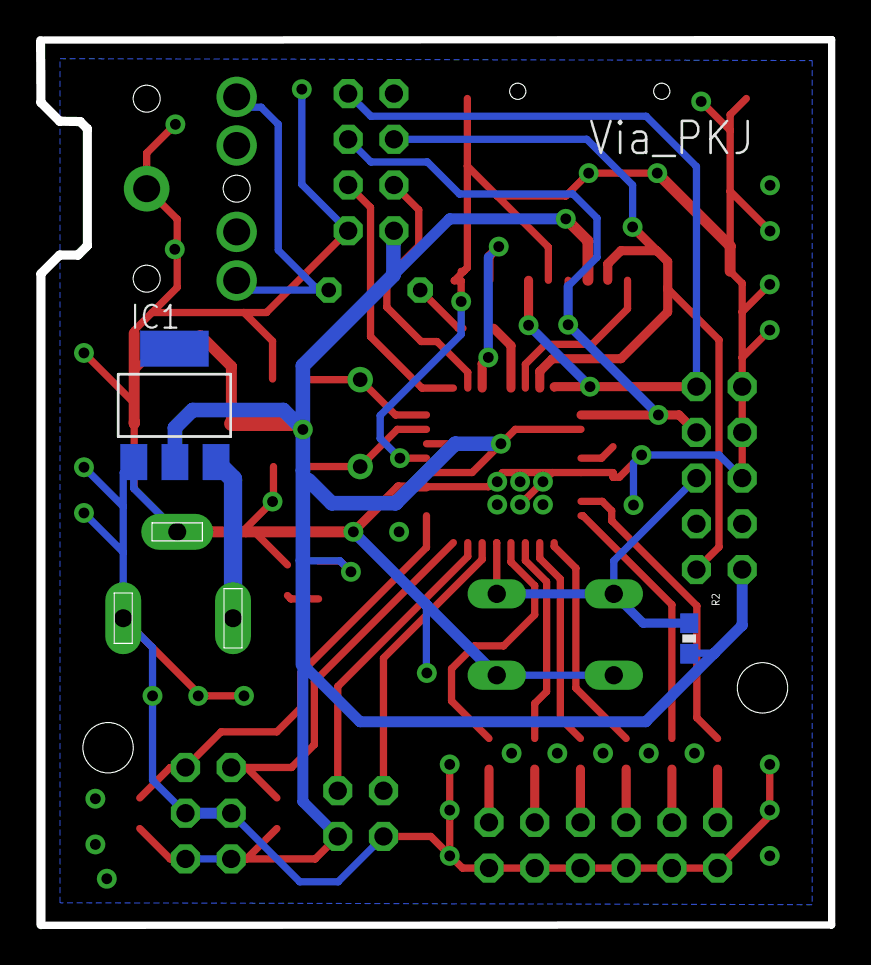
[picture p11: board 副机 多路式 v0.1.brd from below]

Board: 2 copper layers, 43.9 x 49.2 mm, 33 parts (2 on the bottom side), 34 nets.

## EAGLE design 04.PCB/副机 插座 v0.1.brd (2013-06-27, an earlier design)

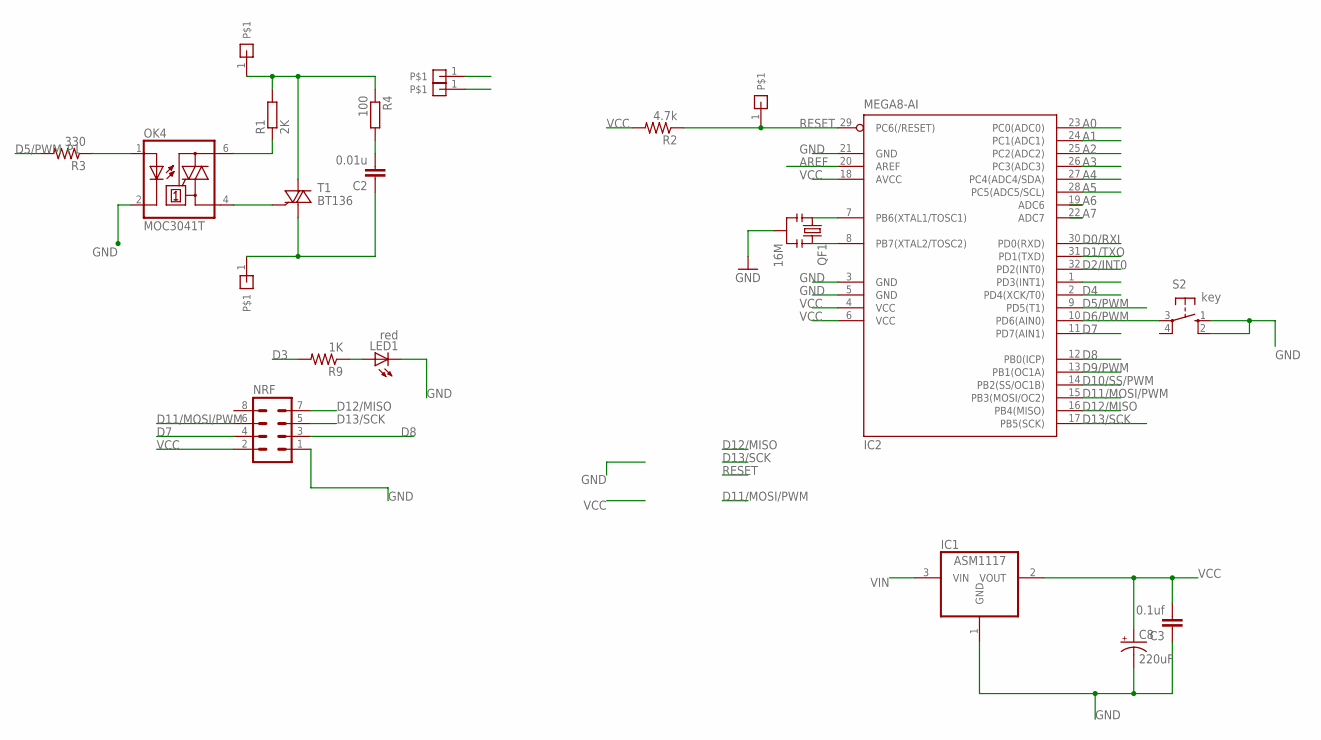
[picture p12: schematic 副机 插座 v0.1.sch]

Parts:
C2: 0.01u; C050-024X044
C3: 0.1uf; 0603-CAP
C8: 220uF; EIA3528
IC1: ASM1117; SOT223
IC2: MEGA8-AI; TQFP32-08
LED1: red; LED3MM
NRF: MA04-2
OK4: MOC3041T; DIL06B
QF1: 16M; RESONATOR-PTH
R1: 2K; 0204/7
R2: 4.7k; 0603-RES
R3: 330; 0603-RES
R4: 100; 0204/7
R9: 1K; 0603-RES
S2: key; B3F-10XX; MPN B3F-1000
T1: BT136; TO220AB
U$1, U$2, U$3, U$4, U$5: PIN1

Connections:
A0: IC2.23 (PC0(ADC0))
A1: IC2.24 (PC1(ADC1))
A2: IC2.25 (PC2(ADC2))
A3: IC2.26 (PC3(ADC3))
A4: IC2.27 (PC4(ADC4/SDA))
A5: IC2.28 (PC5(ADC5/SCL))
A6: IC2.19 (ADC6)
A7: IC2.22 (ADC7)
AREF: IC2.20 (AREF)
D0/RXI: IC2.30 (PD0(RXD))
D1/TXO: IC2.31 (PD1(TXD))
D2/INT0: IC2.32 (PD2(INT0))
D3: IC2.1 (PD3(INT1)), R9.2
D4: IC2.2 (PD4(XCK/T0))
D5/PWM: IC2.9 (PD5(T1)), R3.2
D6/PWM: IC2.10 (PD6(AIN0)), S2.3
D7: IC2.11 (PD7(AIN1)), NRF.4
D8: IC2.12 (PB0(ICP)), NRF.3
D9/PWM: IC2.13 (PB1(OC1A))
D10/SS/PWM: IC2.14 (PB2(SS/OC1B))
D11/MOSI/PWM: IC2.15 (PB3(MOSI/OC2)), NRF.6
D12/MISO: IC2.16 (PB4(MISO)), NRF.7
D13/SCK: IC2.17 (PB5(SCK)), NRF.5
GND: C3.1, C8.C (-), IC1.1 (GND), IC2.3 (GND), IC2.5 (GND), IC2.21 (GND), LED1.K (C), NRF.1, OK4.2 (C), QF1.2, S2.1 (S), S2.2 (S1), U$4.1
IN: R1.2, R4.1, T1.2 (A2), U$2.1
unnamed: OK4.6 (A2), R1.1
unnamed: OK4.4 (A1), T1.3 (G)
unnamed: C2.2, R4.2
unnamed: LED1.A, R9.1
OUT: C2.1, T1.1 (A1), U$1.1
P1: OK4.1 (A), R3.1
PB6: IC2.7 (PB6(XTAL1/TOSC1)), QF1.1
PB7: IC2.8 (PB7(XTAL2/TOSC2)), QF1.3
RESET: IC2.29 (PC6(/RESET)), R2.1, U$5.1
VCC: C3.2, C8.A (+), IC1.2 (VOUT), IC2.4 (VCC), IC2.6 (VCC), IC2.18 (AVCC), NRF.2, R2.2
VIN: IC1.3 (VIN), U$3.1



Board: 2 copper layers, 36.8 x 45.4 mm, 21 parts (7 on the bottom side), 21 nets.

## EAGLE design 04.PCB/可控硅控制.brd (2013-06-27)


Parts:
C1, C2, C3, C4: 0.01u; C050-024X044
OK1, OK2, OK3, OK4: MOC3041M; DIL06
R1, R2, R7, R10: 2K/330; 0204/7
R3, R4, R8, R11: 100; 0204/7
R5, R6, R9, R12: 47; 0204/7
T1, T2, T3, T4: BT136; TO220AB
X2, X3, X4, X5: SMKDSP_1,5/2
X6: 22-23-2051

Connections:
11: OK1.1 (A), R5.1
22: OK3.1 (A), R9.1
33: OK4.1 (A), R12.1
44: OK2.1 (A), R6.1
A1: R1.2, R4.1, T1.2 (A2), X3.2
A2: C2.1, T1.1 (A1), X3.1
B1: R7.2, R8.1, T3.2 (A2), X4.2
B2: C3.1, T3.1 (A1), X4.1
C1: R2.2, R3.1, T2.2 (A2), X2.2
C2: C1.1, T2.1 (A1), X2.1
D1: R10.2, R11.1, T4.2 (A2), X5.2
D2: C4.1, T4.1 (A1), X5.1
GND: OK1.2 (C), OK2.2 (C), OK3.2 (C), OK4.2 (C), X6.1
unnamed: OK1.6 (A2), R1.1
unnamed: OK1.4 (A1), T1.3 (G)
unnamed: C2.2, R4.2
unnamed: OK2.6 (A2), R2.1
unnamed: OK2.4 (A1), T2.3 (G)
unnamed: C1.2, R3.2
unnamed: OK3.6 (A2), R7.1
unnamed: OK3.4 (A1), T3.3 (G)
unnamed: C3.2, R8.2
unnamed: OK4.6 (A2), R10.1
unnamed: OK4.4 (A1), T4.3 (G)
unnamed: C4.2, R11.2
P1: R5.2, X6.5
P2: R9.2, X6.4
P3: R6.2, X6.3
P4: R12.2, X6.2


Board: 2 copper layers, 63.5 x 83.5 mm, 29 parts (0 on the bottom side), 29 nets.

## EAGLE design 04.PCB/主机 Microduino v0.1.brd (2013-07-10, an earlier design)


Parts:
C1, C8: 220uF; E2,5-5
C2, C3: 0.1uf; C025-024X044
IC1, IC2: ASM1117; SOT223
IR: PNA460XM
J1: DCJ0202
JP1: PINHD-1X4; 1X04
JP2: PINHD-1X2; 1X02
R7: 4.7k; AXIAL-0.3
R8: 49.9; AXIAL-0.3
U$1: PING-MICRDUINO-DZ/1009; PIN-MICRODUINO-1009

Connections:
A2: IR.1 (OUT), R7.P$1 (1), U$1.13 (A2)
D20: JP1.2, JP2.2
D21: JP1.1, JP2.1
GND: C1.-, C2.1, C3.1, C8.-, IC1.1 (GND), IC2.1 (GND), IR.2 (GND), J1.2, J1.3, JP1.4, U$1.27 (GND)
unnamed: IR.3 (VCC), R8.P$2 (2)
RESET: U$1.26 (RESET)
V3.3: C1.+, C3.2, IC2.2 (VOUT), IC2.4 (OUT1), JP1.3, U$1.2 (+3V3)
V5.0: C2.2, C8.+, IC1.2 (VOUT), IC1.4 (OUT1), R7.P$2 (2), R8.P$1 (1), U$1.1 (+5V)
VIN: IC1.3 (VIN), IC2.3 (VIN), J1.1



Board: 2 copper layers, 45.7 x 46.7 mm, 13 parts (5 on the bottom side), 8 nets.

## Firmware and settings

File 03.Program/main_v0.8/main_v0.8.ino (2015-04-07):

/*
=================================
 本作品采用知识共享 署名-非商业性使用-相同方式共享 3.0 未本地化版本 许可协议进行许可
 访问 http://creativecommons.org/licenses/by-nc-sa/3.0/ 查看该许可协议
 =================================
 
 github:https://github.com/wasdpkj/Roomduino
 
 硬件：
 主机：MCU：MEGA644PA，网络芯片：ENC28J60，RJ45网口：HR911105A，2.4G无线：nRF24L01，显示屏：nokia5110/oled，红外接收头
 */

#include <PKJ.h>

#include <IRremote.h>
#include <Wire.h>
#include <EtherCard.h>
#define NUM 4

#define jsEEPROM 1000   //EEPROM检查

#define OUT

PKJ pkj;


//请先设置对应引脚定义、显示设备及分辨率不同
#define DEVICE_OLED   //显示设备oled
//#define DEVICE_5110LCD    //显示设备5110

/*-----PIN------*/
//---------------------------------

#define PIN_nrf_CE A5
#define PIN_nrf_CSN A4
#define PIN_enc_CS 8
#define PIN_ir A3
#define PIN_dht 18

//---------------------------------

/*-----LCD------*/
#include "U8glib.h"

//-------字体设置，大、中、小
#define setFont_L u8g.setFont(u8g_font_7x13)
#define setFont_M u8g.setFont(u8g_font_fixed_v0r)
#define setFont_S u8g.setFont(u8g_font_chikitar)
/*
font:  
 u8g.setFont(u8g_font_7x13)
 u8g.setFont(u8g_font_fixed_v0r);
 u8g.setFont(u8g_font_chikitar);
 u8g.setFont(u8g_font_osb21);
 */

//---------------------------------
#ifdef DEVICE_OLED

U8GLIB_SSD1306_128X64 u8g(U8G_I2C_OPT_NONE);	// HW SPI Com: CS = 10, A0 = 9 (Hardware Pins are  SCK = 13 and MOSI = 11)
#define lcd_menu_basicX 5
#define lcd_menu_basicY 11
#define lcd_menu_basicYADD 13
#define lcd_menu_frameX 0
#define lcd_menu_frameY 0
#define lcd_menu_frameW 128
#define lcd_menu_frameH 12
#define lcd_menu_frameYADD 13

#endif
//---------------------------------

//---------------------------------
#ifdef DEVICE_5110LCD

U8GLIB_PCD8544 u8g(10, 7, 5, 6, 4);		// SPI Com: SCK = 13, MOSI = 11, CS = 10, A0 = 9, Reset = 8
#define lcd_menu_basicX 5
#define lcd_menu_basicY 7
#define lcd_menu_basicYADD 8
#define lcd_menu_frameX 0
#define lcd_menu_frameY 0
#define lcd_menu_frameW 83
#define lcd_menu_frameH 8
#define lcd_menu_frameYADD 8

#endif
//---------------------------------

#define u8g_logo_width 128
#define u8g_logo_height 18

const unsigned char u8g_logo_bits[] U8G_PROGMEM = {
  0x00,0x00,0x00,0x00,0x00,0x00,0x00,0x00,0x00,0x00,0x00,0x00,
  0x00,0x00,0x00,0x00,0x00,0x00,0x00,0x00,0x00,0x00,0x00,0x00,
  0x00,0x00,0x00,0x00,0x00,0x00,0x00,0x00,0x00,0xC0,0x01,0xE0,
  0x03,0x00,0x00,0x00,0x00,0x7E,0x00,0xF0,0x01,0x00,0x00,0x00,
  0x00,0xFE,0xF9,0xF7,0x07,0x00,0x00,0x00,0x00,0x3C,0x00,0xF8,
  0x03,0x00,0x00,0x00,0x00,0xFC,0xF9,0xE1,0x03,0x00,0x00,0x00,
  0x00,0x38,0x00,0xF0,0x01,0x00,0x00,0x00,0x00,0xFC,0xFF,0x01,
  0x00,0x00,0x00,0x00,0x00,0x38,0x00,0x00,0x00,0x00,0x00,0x00,
  0x00,0xFC,0xEF,0xF9,0x8F,0xD7,0x73,0xF1,0xC1,0x3B,0x9F,0xFF,
  0xFF,0x1E,0x3E,0x00,0x00,0xBC,0xEF,0xC1,0xE1,0x9F,0xFF,0xDD,
  0xE3,0x3F,0xCC,0xE1,0xF0,0xBF,0x7B,0x00,0x00,0x3C,0xF7,0xE1,
  0xE1,0x9F,0xFF,0xC6,0xF7,0x3E,0x8E,0xF3,0xF0,0xFF,0xF8,0x00,
  0x00,0x3C,0xF3,0xE1,0xF1,0x93,0xFF,0xE6,0xF7,0x3C,0x8F,0xF7,
  0xF0,0xFF,0xFC,0x00,0x00,0x7C,0xF2,0xE1,0xF1,0x83,0x87,0xFE,
  0xF7,0x39,0xFF,0xF7,0xF0,0xFF,0xFF,0x00,0x00,0x7C,0xF0,0xE3,
  0xF3,0xA3,0x03,0xFE,0xF7,0x3F,0xFF,0xF7,0x71,0xFC,0xFF,0x00,
  0x00,0x7C,0xF8,0xE3,0xF3,0xBF,0x03,0xFE,0xE3,0x3F,0xFF,0xF3,
  0x71,0xDC,0x7F,0x00,0x00,0x7E,0xFC,0xE7,0xE3,0xBF,0x03,0xFC,
  0xE3,0x3F,0xFE,0xF3,0x71,0x9C,0x7F,0x00,0x00,0xC1,0x03,0xF8,
  0xCF,0xE7,0x0F,0xF0,0x00,0x7F,0xFC,0xFC,0xFF,0x3E,0x1E,0x00,
  0x00,0x00,0x00,0x00,0x00,0x00,0x00,0x00,0x00,0x00,0x00,0x00,
  0x00,0x00,0x00,0x00,0x00,0x00,0x00,0x00,0x00,0x00,0x00,0x00,
  0x00,0x00,0x00,0x00,0x00,0x00,0x00,0x00,0x00,0x00,0x00,0x00,
  0x00,0x00,0x00,0x00,0x00,0x00,0x00,0x00,0x00,0x00,0x00,0x00
};


#define lcd_delay 5		//屏幕刷新率，以循环为单位
unsigned int lcd_show=0;

/*-----MENU-----*/
boolean  KEY_MENU_enter = false, KEY_MENU_down1x = false, KEY_MENU_up1x = false, KEY_MENU_down10x = false, KEY_MENU_up10x = false;

unsigned int MENU_xuan0, MENU_xuan1, MENU_xuan2, MENU_xuan3;
boolean MENU_xuan0sta, MENU_xuan1sta, MENU_xuan2sta, MENU_xuan3sta;
unsigned int MENUnum0, MENUnum2;
unsigned int MENUval = 0;

boolean setmod = false;
boolean MOD = false, MOD_TS;
uint32_t MOD_TSmil;

unsigned int tk=0;

/*----EEPROM---*/
#include <EEPROM.h>
#define EEPROM_write(address, p) {unsigned int i = 0; byte *pp = (byte*)&(p);for(; i < sizeof(p); i++) EEPROM.write(address+i, pp[i]);}
#define EEPROM_read(address, p)  {unsigned int i = 0; byte *pp = (byte*)&(p);for(; i < sizeof(p); i++) pp[i]=EEPROM.read(address+i);}

struct config_type
{
  unsigned int EEP_C_timesetshi[NUM];
  unsigned int EEP_C_timesetfen[NUM];
  unsigned int EEP_C_timesetdelay[NUM];
  unsigned int EEP_C_dsset[NUM];
  boolean EEP_C_timesta[NUM];
};

/*-------net------*/
static byte mymac[] =
{
  0x2C, 0x81, 0x58, 0x3C, 0xC5, 0x60
};									//MAC
static byte myip[] =
{
  192, 168, 2, 121
};									//IP
static byte gwip[] =
{
  192, 168, 2, 1
};									//网关
static byte dnsip[] =
{
  192, 168, 2, 1
};

byte Ethernet::buffer[900];


//YEELINK---------------------------------------------
#define NET_YEE_request 1400 // milliseconds

PROGMEM char website[] = "api.yeelink.net";

prog_char urlBuf0[] = "/v1.0/device/682/sensor/4018/";  //mod-switch

prog_char urlBuf1[] = "/v1.0/device/682/sensor/3669/";
prog_char urlBuf2[] = "/v1.0/device/682/sensor/3670/";
prog_char urlBuf3[] = "/v1.0/device/682/sensor/3673/";
prog_char urlBuf4[] = "/v1.0/device/682/sensor/3674/";

prog_char urlBuf5[] = "/v1.0/device/682/sensor/4903/";  //tem
prog_char urlBuf6[] = "/v1.0/device/682/sensor/4902/";  //hum

prog_char apiKey[]  = "U-ApiKey: f0644792058aed7c6c20f7fd30d8b7bd";

boolean NET_REPLY = false;
boolean NET_YEE_sw = false;

unsigned int yee[NUM+1];
unsigned int yeenum = 0;

uint32_t NET_YEE_mil;


/*---SEND---*/
#include <RF24Network.h>
#include <RF24.h>
#include <SPI.h>

//* nRF24L01(+) radio attached using Getting Started board *//
RF24 radio(PIN_nrf_CE, PIN_nrf_CSN); //设置24L01的CE和CSN引脚
// Network uses that radio
RF24Network network(radio);
// How often to send 'hello world to the other unit
#define interval 300 //ms
// Address of our node
#define this_node  1
// Address of the other node
#define other_node  0
// When did we last send?
uint32_t last_sent;

struct send_a
{
  uint32_t ms;
  uint32_t sensorDataA;
  uint32_t sensorDataB;
  uint32_t sensorDataC;
  uint32_t sensorDataD;
  uint32_t sensorDataX;
};

/*-------time------*/
#define SECONDS_IN_DAY          86400
#define START_YEAR              1900
#define TIME_ZONE               +8
#define TIME_OUT               10000
#define TIME_REFRESH           300

unsigned int timenian, timeyue, timeri, timeshi, timefen, timemiao, timezhou;  //时钟

static int days_in_month[] =
{
  31, 28, 31, 30, 31, 30, 31, 31, 30, 31, 30, 31
};

static byte ntpServer[] =
{
  193, 204, 114, 232
};
static byte srcPort = 0;

uint32_t timeStamp;
boolean NET_TIME_reply;
boolean NET_WEBSITE_sta;

#define NET_TIME_INTERVAL                1000
#define NET_CS           60000
#define NET_RP           300000
uint32_t TIME_cache = 0, TIME, NET_TIME_cs, NET_TIME_rp;

/*-------timing----*/
boolean KEY_CH_up =  false, KEY_CH_down = false , KEY_CH_ok =  false; //定时2路

uint32_t TIME_loop0,TIME_loop1;

/*-------dht11----*/
#include <dht11.h>
dht11 DHT11;

#define dht11_delay 100
unsigned int tem,hum;
unsigned int dht11_read=0;
boolean dht11_send=false;

/*-------ir------*/
IRrecv irrecv(PIN_ir);
decode_results results;

//===========VOL
boolean C[NUM];
unsigned int C_SW;
//-------------------
unsigned int C_timesetshi[NUM];
unsigned int C_timesetfen[NUM];
unsigned int C_timesetdelay[NUM];
boolean C_timesta[NUM];

boolean C_timedelaysta[NUM];
uint32_t C_timemil[NUM];
//-------------------
unsigned int C_dsset[NUM];

boolean C_dssta[NUM];
boolean C_dsgo[NUM];
unsigned int C_dslast[NUM];
uint32_t C_dsmil[NUM];

unsigned int C_dssw = 0;
//-------------------
unsigned int light;      //风扇档位
unsigned int mod[4];      //风扇档位

void setup()
{
  Serial.begin(115200);

  digitalWrite(12, 1);
  delay(10);

  u8g.setRot180();

  volcdsetup("Via PKJ",10,15);
  delay(2000);
#ifdef DEVICE_OLED
  volcdlogo(0,10);
  delay(2000);
#endif

  //EEPROM-------------------------------------------------  
  volcdsetup("Load EEPROM",10,15);
  delay(1000);

  config_type config_readback;
  EEPROM_read(0, config_readback);

  for(unsigned int a = 0; a < NUM; a++) //循环几路算法
  {
    C_timesetshi[a] = config_readback.EEP_C_timesetshi[a];
    C_timesetfen[a] = config_readback.EEP_C_timesetfen[a];
    C_timesetdelay[a] = config_readback.EEP_C_timesetdelay[a];
    C_dsset[a] = config_readback.EEP_C_dsset[a];
    C_timesta[a] = config_readback.EEP_C_timesta[a];
  }

  //NET------------------------------------------------------
  volcdsetup("Load NETWORK",10,15);
  delay(1000);

  ether.begin(sizeof Ethernet::buffer, mymac, PIN_enc_CS);

  ether.staticSetup(myip, gwip, dnsip);

  ether.printIp("IP:  ", ether.myip);
  ether.printIp("GW:  ", ether.gwip);
  ether.printIp("DNS: ", ether.dnsip);

  if(ether.dnsLookup(website))
  {
    volcdsetup("Yeelink OK",10,15);
    delay(1000);

    NET_WEBSITE_sta = true;
  }
  else
  {
    volcdsetup("Yeelink ERROR",10,15);
    delay(1000);

    NET_WEBSITE_sta = false;
  }
  
  volcdsetup("Load Net Time",10,15);
  delay(1000);

  NET_TIME_reply = true;
  vonettime();

  if(NET_TIME_reply)
  {
    volcdsetup("Net Time ERROR",10,15);
    delay(1000);
  }
  else
  {
    volcdsetup("Net Time OK",10,15);
    delay(1000);
  }
  /*
   while (ether.clientWaitingGw())
   ether.packetLoop(ether.packetReceive());
   */
  volcdsetup("Load nRF",10,15);
  delay(1000);

  SPI.begin();
  radio.begin();
  network.begin(/*channel*/ 90, /*node address*/ this_node);

  NET_YEE_mil = millis(); // start timing out right away


  volcdsetup("Load IR",10,15);
  delay(1000);

  irrecv.enableIRIn();        //开始采集

  volcdsetup("WELCOME!",10,15);
  delay(1000);

}


void loop()
{
  TIME_loop0=millis();

  KEY_MENU_enter = false;
  KEY_MENU_down1x = false;
  KEY_MENU_up1x = false;
  KEY_MENU_down10x = false;
  KEY_MENU_up10x = false;

  KEY_CH_ok =  false;
  KEY_CH_up =  false;
  KEY_CH_down = false;

  MOD_TS = false;

  /*==================Time======================*/
  if (millis() - TIME_cache > TIME_REFRESH || millis() < TIME_cache)        //设置TIME刷新频率
  {
    TIME_cache = millis();
    printDate(uint32_t (timeStamp + 3600 * TIME_ZONE + ((millis() - TIME) / 1000)));
  }

  /*=================end-Time==================*/


  /*=================红外控制=================*/
  if (irrecv.decode(&results))
  {
    voir();
  }

  /*==============end-红外控制=================*/


  /*====================DHT11================*/
  dht11_read++;
  dht11_read=pkj.VOLtiaobian(dht11_read, 0, dht11_delay);
  if(dht11_read==dht11_delay)
  {
//    voDHT11();
  }
  /*====================end-DHT11================*/


  /*================重连服务======================*/
  if(!setmod)
  {
    if(NET_TIME_reply == true && NET_REPLY == false)    //如果setup里时间没连接成功，先重连时间
    {
      if(millis() - NET_TIME_cs > NET_CS || millis() < NET_TIME_cs)
      {
        vonettime();                      //同步时间

        NET_TIME_cs = millis();
        NET_REPLY = true;                        //切换到另一个
      }
    }

    if(NET_WEBSITE_sta == false && NET_REPLY == true)     //如果setup里yeelink服务器没连接上，重连
    {

      if(millis() - NET_TIME_cs > NET_CS || millis() < NET_TIME_cs)
      {
        if(ether.dnsLookup(website))      //连接
        {
          yeenum = 0;
          NET_WEBSITE_sta = true;            //搞定
        }
        else
          NET_WEBSITE_sta = false;           //没搞定

        NET_TIME_cs = millis();
        NET_REPLY = false;                       //切换到另一个
      }
    }

    if(millis() - NET_TIME_rp > NET_RP || millis() < NET_TIME_rp)
    {
      if(ether.dnsLookup(website))      //连接
      {
        yeenum = 0;
        NET_WEBSITE_sta = true;            //搞定
      }
      else
        NET_WEBSITE_sta = false;           //没搞定

      NET_TIME_rp = millis();
    }
  }
  /*===============end-重连服务================*/


  /*==================net=====================*/
  ether.packetLoop(ether.packetReceive());
  word len = ether.packetReceive();
  word pos = ether.packetLoop(len);

  if(pos)
  {
    if(strstr((char *)Ethernet::buffer + pos, "POST") != 0)
    {
      sscanf((char *)strstr((char *)Ethernet::buffer + pos, "lightstatus"), "lightstatus=%d", &light);
      sscanf((char *)strstr((char *)Ethernet::buffer + pos, "mod"), "mod=%d", &mod[0]);
    }


    switch(mod[0])
    {
    case 00:
      MOD=false;
      NET_YEE_sw = true;
      yeenum = 0;
      break;
    case 01:
      MOD=true;
      NET_YEE_sw = true;
      yeenum = 0;
      break;
    }

    if(!MOD)
    {
      if((light%10))
        C_dssta[int(light/10)-1]=false;

      if(light!=0)
      {
        switch(light)
        {
        case 10:
          if(!MOD)
            C[0] = false;
          break;
        case 11:
          if(!MOD)
            C[0] = true;
          break;
        case 20:
          if(!MOD)
            C[1] = false;
          break;
        case 21:
          if(!MOD)
            C[1] = true;
          break;
        case 30:
          if(!MOD)
            C[2] = false;
          break;
        case 31:
          if(!MOD)
            C[2] = true;
          break;
        case 40:
          if(!MOD)
            C[3] = false;
          break;
        case 41:
          if(!MOD)
            C[3] = true;
          break;
        }
      }
      light=0;
    }
    else
      MOD_TS=true;

    BufferFiller bfill = ether.tcpOffset();
    bfill.emit_p(PSTR("HTTP/1.1 200 OK\r\n"
      "Content-Type: text/html\r\n"
      "Pragma: no-cache\r\n\r\n"
      "<!DOCTYPE html><html lang=\"en\"><head><meta charset=\"UTF-8\"/>"
      "<title></title><style type=\"text/css\"> body {background-color:black;} .STYLE0 {background-color:#666666;}.STYLE1 {background-color:#0000FF;} </style></head>"
      "<body><table width=\"500\" border=\"0\"><tr>"
      "<td width=\"102\" height=\"80\" class=\"STYLE$D\"></td><td width=\"102\" height=\"80\" class=\"STYLE$D\"></td>"
      "<td width=\"102\" height=\"80\" class=\"STYLE$D\"></td><td width=\"102\" height=\"80\" class=\"STYLE$D\"></td>"
      "</tr></table>"
      "<table width=\"500\" border=\"0\"><tr><td height=\"10\" class=\"STYLE$D\"></td></tr></table>"
      "</body></html>"), C[0], C[1], C[2], C[3],MOD);
    ether.httpServerReply(bfill.position());
  }
  //==================endnet===================//

  //----------------------------------------------------------------
  if(NET_WEBSITE_sta)
  {
    if (millis() - NET_YEE_mil > NET_YEE_request  || millis() < NET_YEE_mil)    //采集节点时间
    {
      ether.printIp("Server: ", ether.hisip);   //服务器握手

      yeenum++;   //顺序递增
      if(yeenum > 5)
        yeenum = 0;

      switch(yeenum)                            //顺序采集
      {
      case 0:
        if(!NET_YEE_sw)     //网络模式判断未激活时，先执行这个
        {
          ether.browseUrl(urlBuf0, "datapoints", website, apiKey, my_result_cb);  //取得状态
          if(MOD != yee[0])   //如果网络模式改变，归零
          {
            yee[1] = 0, yee[2] = 0, yee[3] = 0, yee[4] = 0;
            C[0] = false, C[1] = false, C[2] = false, C[3] = false;
          }
          MOD = yee[0];   //采集网络模式状态
        }

        else    //网络模式判断激活时，先执行这个，把网络模式状态推出去
        {
          if(MOD != yee[0])
          {
            if(!MOD)
              ether.httpPost (urlBuf0, "datapoints", website, apiKey, "{\"value\":0}", my_result_cb);
            else
              ether.httpPost (urlBuf0, "datapoints", website, apiKey, "{\"value\":1}", my_result_cb);
          }
          NET_YEE_sw = false;   //执行完毕
        }
        break;

      case 1:
        if(MOD)
          ether.browseUrl(urlBuf1, "datapoints", website, apiKey, my_result_cb);    //采集节点
        else
          ether.httpPost (urlBuf1, "datapoints", website, apiKey, "{\"value\":0}", my_result_cb);    //把节点推到关
        break;
      case 2:
        if(MOD)
          ether.browseUrl(urlBuf2, "datapoints", website, apiKey, my_result_cb);   //采集节点
        else
          ether.httpPost (urlBuf2, "datapoints", website, apiKey, "{\"value\":0}", my_result_cb);    //把节点推到关
        break;
      case 3:
        if(MOD)
          ether.browseUrl(urlBuf3, "datapoints", website, apiKey, my_result_cb);    //采集节点
        else
          ether.httpPost (urlBuf3, "datapoints", website, apiKey, "{\"value\":0}", my_result_cb);    //把节点推到关
        break;
      case 4:
        if(MOD)
          ether.browseUrl(urlBuf4, "datapoints", website, apiKey, my_result_cb);    //采集节点
        else
          ether.httpPost (urlBuf4, "datapoints", website, apiKey, "{\"value\":0}", my_result_cb);    //把节点推到关
        break;
      case 5:
        dht11_send=!dht11_send;
        static char buf[20];
        get_send_string(buf);
        if(dht11_send)
          ether.httpPost (urlBuf5, "datapoints", website, apiKey, buf, my_result_cb);    //把节点推到关
        else
          ether.httpPost (urlBuf6, "datapoints", website, apiKey, buf, my_result_cb);    //把节点推到关
        break;
      }

      NET_YEE_mil = millis();
    }

    if(MOD)      //开启网络模式时
    {
      C[0] = yee[1];
      C[1] = yee[2];
      C[2] = yee[3];
      C[3] = yee[4];
    }
  }

  /*===================MOD===================*/
  if(MOD_TS)
    MOD_TSmil = millis();

  /*=================end-MOD=================*/

  if(!MOD)
  {
    /*================定时开启===================*/
    for(unsigned int a = 0; a < NUM; a++) //循环几路算法
    {
      C_timesetshi[a] = pkj.VOLtiaobian(C_timesetshi[a], 0, 23);
      C_timesetfen[a] = pkj.VOLtiaobian(C_timesetfen[a], 0, 59);
      C_timesetdelay[a] = pkj.VOLtiaobian(C_timesetdelay[a], 1, 360);
    }

    for(unsigned int a = 0; a < NUM; a++) //触发
    {
      if(!C_dssta[a] && C_timesta[a] == true && timeshi == C_timesetshi[a] && timefen == C_timesetfen[a] && timemiao == 1)		//没有在定时时，可触发
      {
        C[a] = true;

        C_timedelaysta[a] = true; //持续函数状态
        C_timemil[a] = millis(); //记下开始时间
      }
    }

    for(unsigned int a = 0; a < NUM; a++) //被触发时
    {
      if(C_timedelaysta[a])
      {
        if((millis() - C_timemil[a]) / 1000 / 60 > C_timesetdelay[a])			//超过延时时关闭
        {
          C[a] = false;

          C_timedelaysta[a] == false; //持续函数状态
        }
      }
    }

    //如果某动作需要打断定时，使C_timedelaysta[]函数为假即可

    /*==============end-定时开启================*/


    /*================倒计时===================*/
    if (KEY_CH_up)     //控制数值上升
    {
      C_dssw++;
    }
    if (KEY_CH_down)    //控制数值下降
    {
      C_dssw--;
    }

    C_dssw = pkj.VOLtiaobian(C_dssw, 0, 3);

    for(unsigned int a = 0; a < NUM; a++) //循环几路算法
    {
      C_dsset[a] = pkj.VOLtiaobian(C_dsset[a], 1, 90);
      C_dsgo[a] = false;
    }

    if(KEY_CH_ok)
    {
      C_dsgo[C_dssw] = !C_dsgo[C_dssw];
      C_timedelaysta[C_dssw] = false;					//如果开启倒计时，则打断相应定时
      //C_timesta[C_dssw]=false
    }

    for(unsigned int a = 0; a < NUM; a++) //倒计时
    {
      if (C_dsgo[a] == true && (C_dssta[a] == false && C[a] == false))    //C[]为零时可触发计时
      {
        C_dsmil[a] = millis();
        C[a] = true;          //开始执行
        C_dssta[a] = true;    //开始计时
      }

      else if (C_dsgo[a] == true && (C_dssta[a] == true || C[a] == true))   //C[]为1时或计时开始后，再次触发则停止计时、
      {
        C[a] = false;
        C_dssta[a] = false;   //停止计时
      }

      if((millis() - C_dsmil[a]) / 1000 > C_dsset[a] * 60 && C_dssta[a] == true) //大于设置
      {
        C[a] = false;         //停止执行
        C_dssta[a] = false;   //停止计时
      }

      C_dslast[a] = (C_dsset[a] * 60 - (millis() - C_dsmil[a]) / 1000);
    }
    /*=============end-倒计时===================*/
  }

  /*=====================MENU===================*/
  vomenu();

  /*====================end-MENU================*/


  /*=====================LCD===================*/
  lcd_show++;
  lcd_show=pkj.VOLtiaobian(lcd_show, 0, lcd_delay);
  if(lcd_show==lcd_delay)
  {
    u8g.firstPage();
    do
    {
      if(setmod)
        menu();
      else
        draw();
    }
    while( u8g.nextPage() );
  }

  /*===================end-LCD================*/


  /*==================SEND======================*/
  vosend();

  /*================end-SEND=====================*/

  TIME_loop1=millis()-TIME_loop0;
}


void get_send_string(OUT char *p)
{
  unsigned int cache;

  switch(dht11_send)
  {
  case false:
    cache = hum;
    break;
  case true:
    cache = tem;
    break;
  }

  sprintf(p, "{\"value\":%d}", cache);
}
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

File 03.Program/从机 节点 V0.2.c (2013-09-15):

#include <EEPROM.h>
#include <RF24Network.h>
#include <RF24.h>
#include <SPI.h>

#define led 6
#define key 2
#define POWER 5

//EEPROM--------------------------
#define EEPROM_write(address, p) {int i = 0; byte *pp = (byte*)&(p);for(; i < sizeof(p); i++) EEPROM.write(address+i, pp[i]);}
#define EEPROM_read(address, p)  {int i = 0; byte *pp = (byte*)&(p);for(; i < sizeof(p); i++) pp[i]=EEPROM.read(address+i);}

struct config_type
{
  int EEPROM_NUM;
};

boolean EEPROM_STA=false,EEPROM_CACHE=false;

// nRF24L01(+) radio attached using Getting Started board 
RF24 radio(8,7); //设置24L01的CE和CSN引脚
// Network uses that radio
RF24Network network(radio);
// Address of our node
const uint16_t this_node = 0;
// Address of the other node
const uint16_t other_node = 1;
// Structure of our payload
struct payload_a
{
  uint32_t ms;
  uint32_t sensorDataA;
  uint32_t sensorDataB;
  uint32_t sensorDataC;
  uint32_t sensorDataD;
  uint32_t sensorDataX;
};

// ethernet interface mac address
boolean C[4];
int tempX;
uint32_t time;

int NUM,ledNUM=0;
boolean STA,ledSTA=false;
long TIME_JS,TIME_LED;

int DELAY;

void setup(void)
{
  Serial.begin(9600);

  pinMode(key,INPUT_PULLUP);		//上拉电阻
  pinMode(led,OUTPUT);
  pinMode(POWER,OUTPUT);

  /*EEPROM读取赋值*/
  config_type config_readback;
  EEPROM_read(0, config_readback);

  NUM = config_readback.EEPROM_NUM;

  SPI.begin();
  radio.begin();
  network.begin(/*channel*/ 90, /*node address*/ this_node);
  if(NUM!=0 && NUM!=1 && NUM!=2 && NUM!=3)
  {
    NUM=0;
    eeprom_write();					//写入EEPROM
  }

}

void loop(void)
{
  digitalWrite(POWER,STA);
  digitalWrite(led,ledSTA);


  //指示灯----------------------------------
  if(millis()-TIME_LED>DELAY)
  {
    ledSTA=!ledSTA;
    ledNUM++;
    if(ledNUM>(NUM*2)+1)			//亮灭
    {
      ledSTA=false;
      DELAY=2500;					//间隔
      ledNUM=0;
    }
    else
      DELAY=300;

    TIME_LED=millis();
    /*
     Serial.print(" NUM:");
     Serial.print(ledNUM);
     Serial.print(" STA:");
     Serial.println(ledSTA);
     */
  }	


  //按键判断--------------------------------
  if(boolean(digitalRead(key)))		//配置键未按下时高电平
    TIME_JS=millis();

  if(millis()-TIME_JS>2000)			//超过两秒
  {
    if(tempX!=0)					//主机是否在配置状态
    {
      NUM=tempX-1;					//第几路
      EEPROM_CACHE=true;			//EEPROM状态判断开启
      ledSTA=!ledSTA;				//闪动
      delay(80);
      TIME_LED=millis();
    }
  }
  else
    EEPROM_STA=false;				//松开按键时


  if(EEPROM_CACHE!=EEPROM_STA)		//判断是否在按键松开时
  {
    eeprom_write();					//写入EEPROM
    EEPROM_CACHE=false;				//归为
  }

  EEPROM_STA=EEPROM_CACHE;			//同步

  STA=C[NUM];		//开关赋值


  // Pump the network regularly
  network.update();
  // Is there anything ready for us?
  while ( network.available() )
  {
    // If so, grab it and print it out
    RF24NetworkHeader header;
    payload_a payloada;
    network.read(header,&payloada,sizeof(payloada));

    if(payloada.ms-time>0)
    {
      time=payloada.ms;
      C[0]=payloada.sensorDataA;
      C[1]=payloada.sensorDataB;
      C[2]=payloada.sensorDataC;
      C[3]=payloada.sensorDataD;
      tempX=payloada.sensorDataX;
    }
  }

  /*
  Serial.print("            STA:");
   Serial.print(STA);
   Serial.print(" / TempA:");
   Serial.print(C[0]);
   Serial.print("  TempB:");
   Serial.print(C[1]);
   Serial.print("  TempC:");
   Serial.print(C[2]);
   Serial.print("  TempD:");
   Serial.print(C[3]);
   Serial.print("  TempX:");
   Serial.print(tempX);
   Serial.print("  Time:");
   Serial.println(time/1000);
   */
}

void eeprom_write()
{
  config_type config;  		// 定义结构变量config，并定义config的内容
  config.EEPROM_NUM = NUM;

  EEPROM_write(0, config); 	// 变量config存储到EEPROM，地址0写入
}

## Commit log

2013-06-27 V0.4主机程序无论用5110还是oled，写在一个程序了，在define中选择
    主机程序无论用5110还是oled，写在一个程序了，在define中选择
2013-06-29 V0.5 修正了菜单显示bug
    V0.5 修正了菜单显示bug
2013-06-29 V0.5
    V0.5 修正了显示问题
2013-06-30 V0.6更新了温湿度查错
    V0.6更新了温湿度查错
2013-06-30 增加dht11的库
    增加dht11的库
2013-06-30 更新了温湿度查错
    更新了温湿度查错
2013-07-10 更新了Microduino面包版PCB
    更新了Microduino面包版PCB
    [主机 Microduino v0.1.brd, 主机 Microduino v0.1.sch]
2013-07-13 解决了millis()溢出问题
    解决了millis()溢出问题
2013-07-17 优化了变量
    优化了变量
2013-08-16 更新文件夹名称
    [主机 Microduino v0.1.brd, 主机 Microduino v0.1.sch, 主机 v0.1.brd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]
2013-09-02 更新了几个新pcb
    更新了几个新pcb
    [主机 Microduino v0.5.brd, 主机 Microduino v0.5.sch, 主机 v0.2.brd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]
2013-11-09 程序引脚请自己定义
    [主机 Microduino v1.0.brd, 主机 Microduino v1.0.sch, 主机 v0.2.brd]
2013-11-09 单片机改用5v供电，ISP下载口也是5v电压
    [副机 插座 v1.0.brd, 副机 插座 v1.0.sch]
